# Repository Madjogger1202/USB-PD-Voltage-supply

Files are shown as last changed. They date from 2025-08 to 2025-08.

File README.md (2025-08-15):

# USB-PD Voltage supply

<table align="center">
  <tr>
    <td>
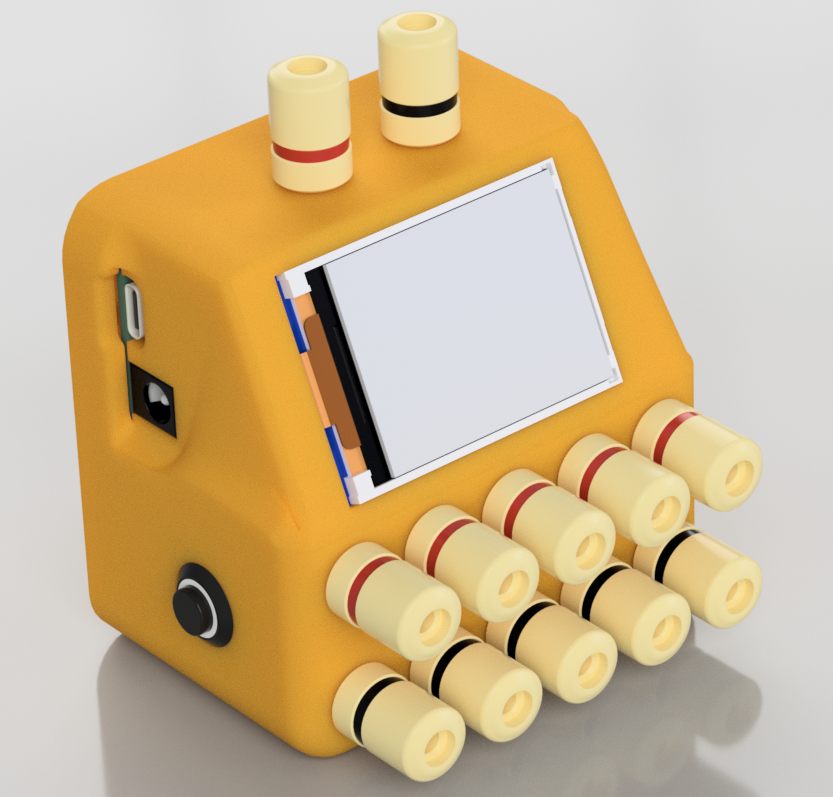
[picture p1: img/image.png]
      
    </td> 
    <td>
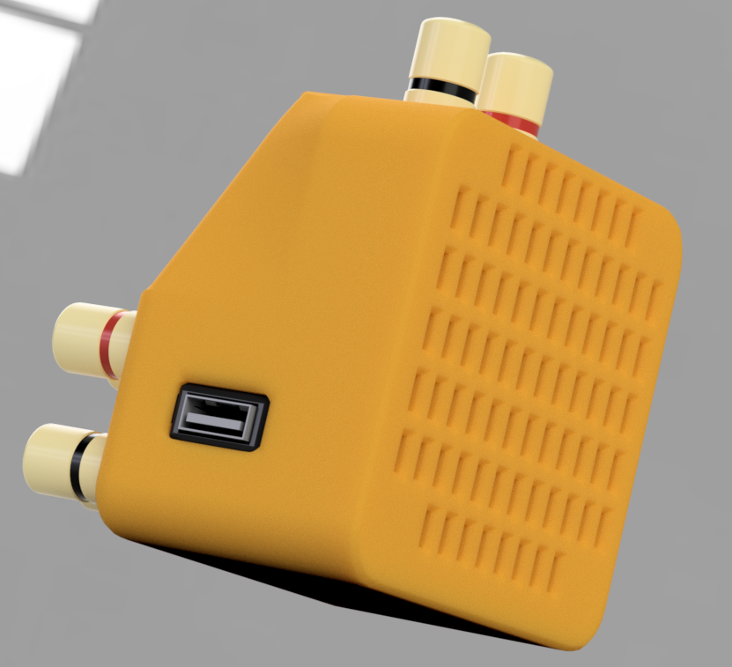
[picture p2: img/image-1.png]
      
    </td>
  </tr>
</table>

# Universal Programmable Power Supply Module

A compact, network-enabled power solution designed for debugging modern semiconductor components (e.g., PCIe switches, ASICs, and multi-voltage SoCs). Replaces traditional bench power supplies with a single integrated unit featuring precise voltage control, remote accessibility, and modular expandability.

---

> [!IMPORTANT]
> Project wasn't produced and tested yet.

## Key Features

- **Dual Adjustable DC-DC Outputs**  
  0.8–22 V, 6 A per channel (TPS55289RYQR controllers)  
- **Dual Fixed 5 V Outputs**  
  3 A each (LMR16030PDDAR), one for system logic, one for LDO input  
- **Low-Noise LDO Output**  
  0.5–5 V, 3 A (TPS7A5701RTER with TPL0501-100DCNR digital potentiometer)  
- **Universal Input**  
  Accepts 5–20 V via USB-C Power Delivery (STUSB4500QTR) or barrel jack (max 21 V input)  
- **Network Control**  
  ESP32-C3-based management with secure Wi-Fi/BLE, web interface, and Telegram bot  
- **Precision Monitoring**  
  ±1% current sensing via INA180A2 and ESP32-C3 ADC  
- **Expandable I/O**  
  Integrated GPIO expander for external modules or physical control buttons  
- **PCB Stackup**  
  4-layer board designed for stable power distribution, reduced noise, and improved thermal performance. Layers include dedicated power and ground planes for enhanced signal integrity. 
---

## Technical Specifications

| **Parameter** | **Details** |
|---|---|
| **Input** | USB-C PD (20 V/5 A) or 5.5×2.5 mm barrel jack (5–20 V) |
| **Adjustable Rails** | 2× 0.8–22 V / 6 A (DC-DC), 1× 0.5–5 V / 3 A (LDO) |
| **Fixed Rails** | 2× 5 V / 3 A (DC-DC) |
| **Control Interface**  | ESP32-C3 (Wi-Fi 4, BLE 5), REST API, web UI, Telegram bot |
| **Display** | 2.0" ST7789 (320×240) TFT with real-time voltage/current monitoring |
| **Current Sensing** | INA180A2 amplifier with 12-bit ADC resolution |
| **Safety Limits** | Input voltage ≤ 21 V; overcurrent/overvoltage protection per channel |

---

## PCB
<div align="center">
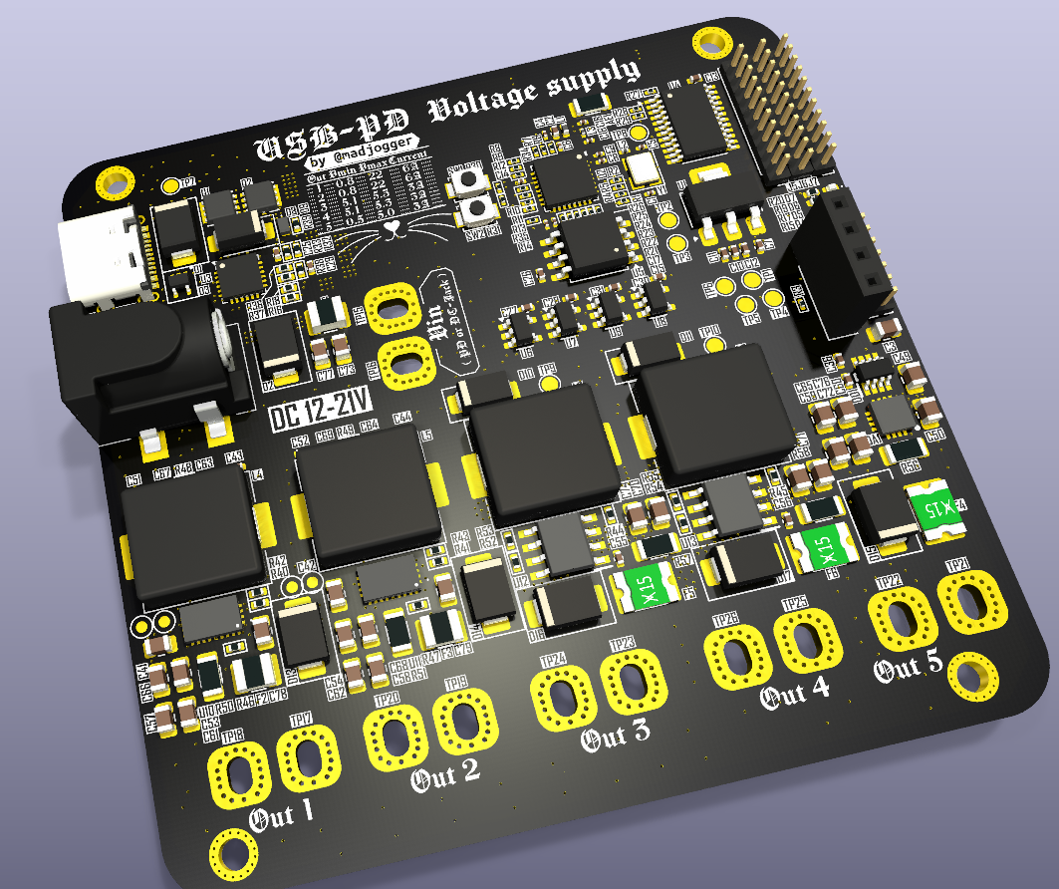
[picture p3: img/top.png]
Top view
  
  &nbsp;&nbsp;&nbsp;&nbsp;
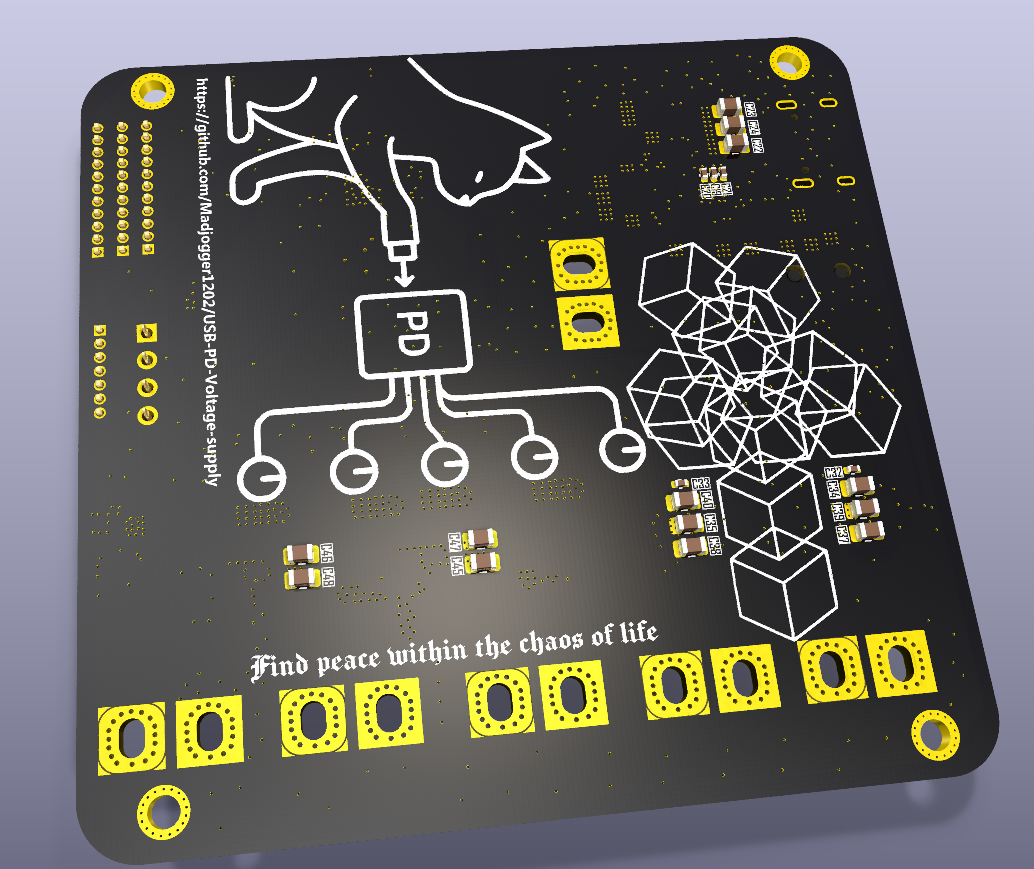
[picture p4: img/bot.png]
Bottom view
  
  &nbsp;&nbsp;&nbsp;&nbsp;
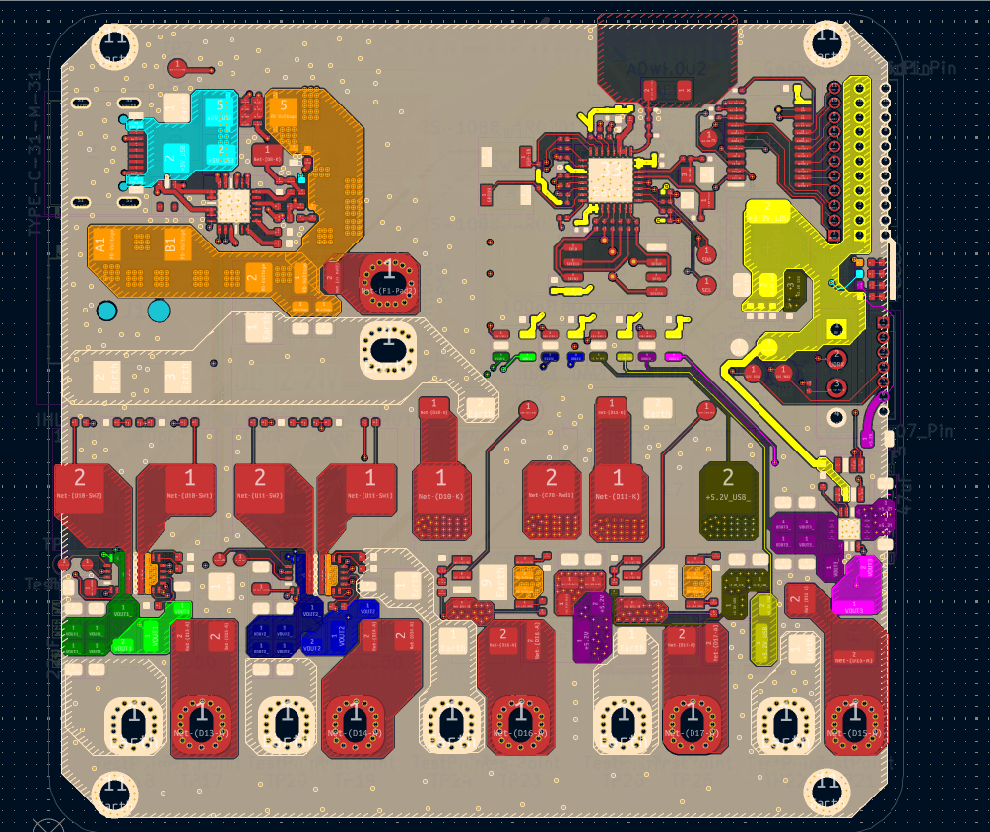
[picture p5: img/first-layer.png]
First layer
  
</div>

## Functional diagram
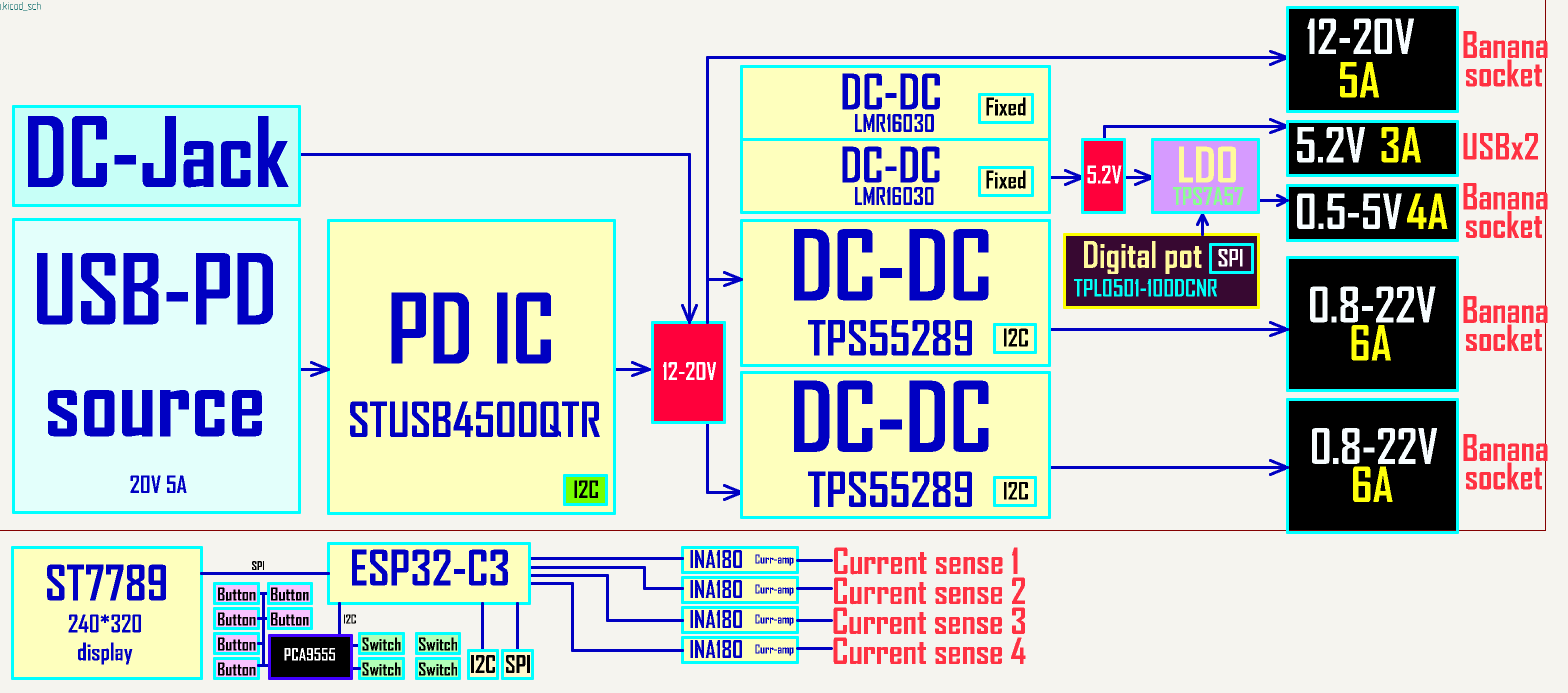
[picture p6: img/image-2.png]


## Standard Configuration

- 6× banana jack terminal pairs 
- 2.0" ST7789 color display (320×240 resolution)  
- USB-A port for peripheral connectivity  
- 12 mm illuminated push-button (power control)    

---

## Development Ecosystem

- **Schematic & PCB Design**: KiCad 9.0 (4-layer stackup)  
- **3D Modeling**: Fusion 360 
- **Firmware**: PlatformIO (Arduino)  

---

## Use Cases

- General-purpose bench power supply
- PCIe switch and high-speed interface debugging  
- Multi-rail ASIC/FPGA prototyping  
- Low-noise analog/digital mixed-signal validation  
- Automated test environments requiring remote power cycling  

---

## Documentation

  - [Schematics](USB-PD-Voltage-supply.pdf)  
  - [Interactive HTML BOM](BOM/USB-PD-Voltage-supply-Interactive-BOM.html)  
  - [3D model with case](3D/USB-PD-Voltage-supply-with-case.step)  
  - Code for PlatformIO coming soon

> **Note**: Input voltage must not exceed 21 V. Always verify load requirements before operation.

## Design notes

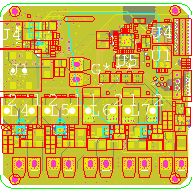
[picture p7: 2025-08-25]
USB-PD-Voltage-supply simulation/USB-PD-Voltage-supply simulation/Model/DS/Image/Model.bmp

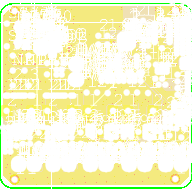
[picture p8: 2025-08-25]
USB-PD-Voltage-supply simulation/USB-PD-Voltage-supply simulation/Model/PCBS/Model.bmp

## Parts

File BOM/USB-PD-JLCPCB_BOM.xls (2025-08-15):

Comment | Designator | Footprint | JLCPCB Part#(optional)
ADWH002 | AE1 | 1206_3216Metric | C22467691
24pF | C1,C5 | 0201_0603Metric | C285108
10uF | C2,C11 | 0402_1005Metric | C76991
22uF 25V | C3,C22,C23,C24,C34,C35,C37,C38,C39,C40,C41,C42,C45,C46,C47,C48,C53,C54,C57,C58,C61,C62,C66,C68,C73,C77,C78,C79 | 0805_2012Metric | C45783
100nF | C4,C8,C14,C15 | 0201_0603Metric | C49062
1uF | C6,C9,C17 | 0201_0603Metric | C53067
22uF | C7,C10 | 0402_1005Metric | C105226
100nF | C12,C13,C26,C27,C28,C29,C30,C31,C32,C33,C36,C43,C44,C51,C52,C55,C56 | 0402_1005Metric | C1581
1.2pF | C16 | 0201_0603Metric | C85895
1.8pF | C18 | 0201_0603Metric | C285155
1uF | C19,C20,C21,C25 | 0402_1005Metric | C77009
47uF | C49,C50,C59,C65,C70,C71,C72,C74,C75,C76 | 0805_2012Metric | C16780
4.7uF | C60 | 0402_1005Metric | C5718966
10pF | C63,C64 | 0402_1005Metric | C1545
2.2nF | C67,C69 | 0402_1005Metric | C1531
SMBJ40CA | D1,D2,D13,D14,D15,D16,D17 | SMB | C726876
ESDA25W5 | D3 | SOT-353 | C2931117
LED | D4,D5,D6,D7 | 402 | C71911
SS34 | D8,D10,D11 | SMA | C8678
ESDA25P35-1U1M | D9 | ESDA25P35-1U1M:ESDA25P351U1M | C1974707
TPS7A5701RTER | DA1 | TPS7A57:TPS7A57 | C5220126
TPL0501-100DCNR | DD1 | TPL0501-100DCNR:SOT65P280X145-8N | C131323
SL1210650 | F1,F2,F3 | Fuse:Fuse_1210_3225Metric | C70191
SMD1812P350TF | F4,F5,F6 | Fuse:Fuse_1812_4532Metric | C20815
DC-005-5A-2.5-SMT | J1 | DC-005-5A:DC-005-5A | C319133
Conn_01x07_Pin | J2 | Connector_PinHeader_1.27mm:PinHeader_1x07_P1.27mm_Vertical | C22438104
Conn_01x04_Pin | J3 | Connector_PinSocket_2.54mm:PinSocket_1x04_P2.54mm_Vertical | C5116483
TYPE-C-31-M-31 | J4 | Connector_USB:USB_C_Receptacle_G-Switch_GT-USB-7010ASV | C2760486
2nH | L1 | Inductor_SMD:L_0402_1005Metric | C76769
24nH | L2 | Inductor_SMD:L_0201_0603Metric | C206441
3nH | L3 | Inductor_SMD:L_0201_0603Metric | C87524
IHLP4040DZER4R7M01 | L4,L5 | Inductor_SMD:L_APV_APH1040 | C845077
IHLP4040DZER100M01 | L6,L7 | Inductor_SMD:L_APV_APH1040 | C845065
STL6P3LLH6 | Q1,Q2 | STL6P3LLH6:STL8N10F7 | C22366875
4.7K | R1,R2 | PCM_Resistor_SMD_AKL:R_0402_1005Metric | C25900
499 | R3 | PCM_Resistor_SMD_AKL:R_0201_0603Metric | C4125
0 | R4,R5,R6,R7,R8,R9,R10,R11,R12,R13,R14,R21,R22,R23,R24,R25,R26,R27,R28,R29 | PCM_Resistor_SMD_AKL:R_0201_0603Metric | C17168
620 | R15 | 0402_1005Metric | C4961
100K | R16,R18,R37,R52,R54 | PCM_Resistor_SMD_AKL:R_0402_1005Metric | C25741
1.5K | R17 | 0402_1005Metric | C25867
10K | R19,R20 | 0402_1005Metric | C25744
10K | R30,R31 | PCM_Resistor_SMD_AKL:R_0201_0603Metric | C100126
470 | R32 | PCM_Resistor_SMD_AKL:R_0402_1005Metric | C25117
1K | R33,R39 | PCM_Resistor_SMD_AKL:R_0402_1005Metric | C11702
100K | R34,R35 | PCM_Resistor_SMD_AKL:R_0201_0603Metric | C100127
22K | R36 | PCM_Resistor_SMD_AKL:R_0402_1005Metric | C25768
100 | R38 | PCM_Resistor_SMD_AKL:R_0402_1005Metric | C25076
0 | R40,R41 | PCM_Resistor_SMD_AKL:R_0402_1005Metric | C17168
82K | R42,R43 | PCM_Resistor_SMD_AKL:R_0402_1005Metric | C4142
49.9K | R44,R45 | PCM_Resistor_SMD_AKL:R_0402_1005Metric | C25897
10K | R46,R47 | PCM_Resistor_SMD_AKL:R_0402_1005Metric | C25531
71.5K | R48,R49 | PCM_Resistor_SMD_AKL:R_0402_1005Metric | C273328
0.01 | R50,R51,R56,R57,R58 | 1206_3216Metric | C364375
16.9K | R53,R55 | PCM_Resistor_SMD_AKL:R_0402_1005Metric | C25858
TS-1088-AR02016 | SW1,SW2 | Button_Switch_SMD:SW_SPST_B3U-1000P | C720477
AP1117-33 | U1 | Package_TO_SOT_SMD:SOT-223-3_TabPin2 | C5400
ESP32-C3 | U2 | Package_DFN_QFN:QFN-32-1EP_5x5mm_P0.5mm_EP3.7x3.7mm | C2838500
STUSB4500QTR | U3 | Package_DFN_QFN:QFN-24-1EP_4x4mm_P0.5mm_EP2.7x2.7mm | STUSB4500QTR
PCA9555PW | U4 | Package_SO:TSSOP-24_4.4x7.8mm_P0.65mm | C128392
W25Q128JVS | U5 | Package_SO:SOIC-8_5.3x5.3mm_P1.27mm | C97521
INA180A2 | U6,U7,U8,U9 | Package_TO_SOT_SMD:SOT-23-5 | SOT-23-5
TPS55289RYQR | U10,U11 | TPS55289RYQR:TPS55289RYQR | C5942077
LMR16030PDDAR | U12,U13 | LMR16030:LMR16030 | C90665
X322540MPB4SI | Y1 | Crystal:Crystal_SMD_3225-4Pin_3.2x2.5mm | C9010

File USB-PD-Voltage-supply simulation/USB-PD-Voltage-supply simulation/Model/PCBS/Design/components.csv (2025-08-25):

refdes | partname | type | Arrow_Part_Number | Arrow_Price/Stock | Datasheet | Description | Height | Manufacturer_Name | Manufacturer_Part_Number | Mouser_Part_Number | Mouser_Price/Stock | Value | Voltage
AE1 | Resistor_SMD_R_1206_3216Metric |  |  |  |  | Ceramic chip antenna with pin for PCB trace |  |  |  |  |  | ADWH002
C1 | Capacitor_SMD_C_0201_0603Metric | C |  |  |  | Unpolarized capacitor |  |  |  |  |  | 24pF
C10 | Capacitor_SMD_C_0402_1005Metric | C |  |  |  | Unpolarized capacitor |  |  |  |  |  | 22uF
C11 | Capacitor_SMD_C_0402_1005Metric | C |  |  |  | Unpolarized capacitor |  |  |  |  |  | 10uF
C12 | Capacitor_SMD_C_0402_1005Metric | C |  |  |  | Unpolarized capacitor |  |  |  |  |  | 100nF
C13 | Capacitor_SMD_C_0402_1005Metric | C |  |  |  | Unpolarized capacitor |  |  |  |  |  | 100nF
C14 | Capacitor_SMD_C_0201_0603Metric | C |  |  |  | Unpolarized capacitor |  |  |  |  |  | 100nF
C15 | Capacitor_SMD_C_0201_0603Metric | C |  |  |  | Unpolarized capacitor |  |  |  |  |  | 100nF
C16 | Capacitor_SMD_C_0201_0603Metric | C |  |  |  | Unpolarized capacitor |  |  |  |  |  | 1.2pF
C17 | Capacitor_SMD_C_0201_0603Metric | C |  |  |  | Unpolarized capacitor |  |  |  |  |  | 1uF
C18 | Capacitor_SMD_C_0201_0603Metric | C |  |  |  | Unpolarized capacitor |  |  |  |  |  | 1.8pF
C2 | Capacitor_SMD_C_0402_1005Metric | C |  |  |  | Unpolarized capacitor |  |  |  |  |  | 10uF
C25 | Capacitor_SMD_C_0402_1005Metric | C |  |  |  | Unpolarized capacitor |  |  |  |  |  | 1uF
C26 | Capacitor_SMD_C_0402_1005Metric | C |  |  |  | Unpolarized capacitor |  |  |  |  |  | 100nF
C27 | Capacitor_SMD_C_0402_1005Metric | C |  |  |  | Unpolarized capacitor |  |  |  |  |  | 100nF
C28 | Capacitor_SMD_C_0402_1005Metric | C |  |  |  | Unpolarized capacitor |  |  |  |  |  | 100nF
C29 | Capacitor_SMD_C_0402_1005Metric | C |  |  |  | Unpolarized capacitor |  |  |  |  |  | 100nF
C3 | Capacitor_SMD_C_0805_2012Metric | C |  |  |  | Unpolarized capacitor |  |  |  |  |  | 22uF | 25V
C30 | Capacitor_SMD_C_0402_1005Metric | C |  |  |  | Unpolarized capacitor |  |  |  |  |  | 100nF
C31 | Capacitor_SMD_C_0402_1005Metric | C |  |  |  | Unpolarized capacitor |  |  |  |  |  | 100nF
C36 | Capacitor_SMD_C_0402_1005Metric | C |  |  |  | Unpolarized capacitor |  |  |  |  |  | 100nF
C4 | Capacitor_SMD_C_0201_0603Metric | C |  |  |  | Unpolarized capacitor |  |  |  |  |  | 100nF
C41 | Capacitor_SMD_C_0805_2012Metric | C |  |  |  | Unpolarized capacitor |  |  |  |  |  | 22uF | 25V
C42 | Capacitor_SMD_C_0805_2012Metric | C |  |  |  | Unpolarized capacitor |  |  |  |  |  | 22uF | 25V
C43 | Capacitor_SMD_C_0402_1005Metric | C |  |  |  | Unpolarized capacitor |  |  |  |  |  | 100nF
C44 | Capacitor_SMD_C_0402_1005Metric | C |  |  |  | Unpolarized capacitor |  |  |  |  |  | 100nF
C49 | Capacitor_SMD_C_0805_2012Metric | C |  |  |  | Unpolarized capacitor |  |  |  |  |  | 47uF | 6.3V
C5 | Capacitor_SMD_C_0201_0603Metric | C |  |  |  | Unpolarized capacitor |  |  |  |  |  | 24pF
C50 | Capacitor_SMD_C_0805_2012Metric | C |  |  |  | Unpolarized capacitor |  |  |  |  |  | 47uF | 6.3V
C51 | Capacitor_SMD_C_0402_1005Metric | C |  |  |  | Unpolarized capacitor |  |  |  |  |  | 100nF
C52 | Capacitor_SMD_C_0402_1005Metric | C |  |  |  | Unpolarized capacitor |  |  |  |  |  | 100nF
C53 | Capacitor_SMD_C_0805_2012Metric | C |  |  |  | Unpolarized capacitor |  |  |  |  |  | 22uF | 25V
C54 | Capacitor_SMD_C_0805_2012Metric | C |  |  |  | Unpolarized capacitor |  |  |  |  |  | 22uF | 25V
C55 | Capacitor_SMD_C_0402_1005Metric | C |  |  |  | Unpolarized capacitor |  |  |  |  |  | 100nF
C56 | Capacitor_SMD_C_0402_1005Metric | C |  |  |  | Unpolarized capacitor |  |  |  |  |  | 100nF
C57 | Capacitor_SMD_C_0805_2012Metric | C |  |  |  | Unpolarized capacitor |  |  |  |  |  | 22uF | 25V
C58 | Capacitor_SMD_C_0805_2012Metric | C |  |  |  | Unpolarized capacitor |  |  |  |  |  | 22uF | 25V
C59 | Capacitor_SMD_C_0805_2012Metric | C |  |  |  | Unpolarized capacitor |  |  |  |  |  | 47uF | 6.3V
C6 | Capacitor_SMD_C_0201_0603Metric | C |  |  |  | Unpolarized capacitor |  |  |  |  |  | 1uF
C60 | Capacitor_SMD_C_0402_1005Metric | C |  |  |  | Unpolarized capacitor |  |  |  |  |  | 4.7uF | 6.3V
C61 | Capacitor_SMD_C_0805_2012Metric | C |  |  |  | Unpolarized capacitor |  |  |  |  |  | 22uF | 25V
C62 | Capacitor_SMD_C_0805_2012Metric | C |  |  |  | Unpolarized capacitor |  |  |  |  |  | 22uF | 25V
C63 | Capacitor_SMD_C_0402_1005Metric | C |  |  |  | Unpolarized capacitor |  |  |  |  |  | 10pF
C64 | Capacitor_SMD_C_0402_1005Metric | C |  |  |  | Unpolarized capacitor |  |  |  |  |  | 10pF
C65 | Capacitor_SMD_C_0805_2012Metric | C |  |  |  | Unpolarized capacitor |  |  |  |  |  | 47uF | 6.3V
C66 | Capacitor_SMD_C_0805_2012Metric | C |  |  |  | Unpolarized capacitor |  |  |  |  |  | 22uF | 25V
C67 | Capacitor_SMD_C_0402_1005Metric | C |  |  |  | Unpolarized capacitor |  |  |  |  |  | 2.2nF
C68 | Capacitor_SMD_C_0805_2012Metric | C |  |  |  | Unpolarized capacitor |  |  |  |  |  | 22uF | 25V
C69 | Capacitor_SMD_C_0402_1005Metric | C |  |  |  | Unpolarized capacitor |  |  |  |  |  | 2.2nF
C7 | Capacitor_SMD_C_0402_1005Metric | C |  |  |  | Unpolarized capacitor |  |  |  |  |  | 22uF
C70 | Capacitor_SMD_C_0805_2012Metric | C |  |  |  | Unpolarized capacitor |  |  |  |  |  | 47uF | 6.3V
C71 | Capacitor_SMD_C_0805_2012Metric | C |  |  |  | Unpolarized capacitor |  |  |  |  |  | 47uF | 6.3V
C72 | Capacitor_SMD_C_0805_2012Metric | C |  |  |  | Unpolarized capacitor |  |  |  |  |  | 47uF | 6.3V
C73 | Capacitor_SMD_C_0805_2012Metric | C |  |  |  | Unpolarized capacitor |  |  |  |  |  | 22uF | 25V
C74 | Capacitor_SMD_C_0805_2012Metric | C |  |  |  | Unpolarized capacitor |  |  |  |  |  | 47uF | 6.3V
C75 | Capacitor_SMD_C_0805_2012Metric | C |  |  |  | Unpolarized capacitor |  |  |  |  |  | 47uF | 6.3V
C76 | Capacitor_SMD_C_0805_2012Metric | C |  |  |  | Unpolarized capacitor |  |  |  |  |  | 47uF | 6.3V
C77 | Capacitor_SMD_C_0805_2012Metric | C |  |  |  | Unpolarized capacitor |  |  |  |  |  | 22uF | 25V
C78 | Capacitor_SMD_C_0805_2012Metric | C |  |  |  | Unpolarized capacitor |  |  |  |  |  | 22uF | 25V
C79 | Capacitor_SMD_C_0805_2012Metric | C |  |  |  | Unpolarized capacitor |  |  |  |  |  | 22uF | 25V
C8 | Capacitor_SMD_C_0201_0603Metric | C |  |  |  | Unpolarized capacitor |  |  |  |  |  | 100nF
C9 | Capacitor_SMD_C_0201_0603Metric | C |  |  |  | Unpolarized capacitor |  |  |  |  |  | 1uF
D1 | PCM_Diode_SMD_AKL_D_SMB_TVS |  |  |  | https://www.tme.eu/Document/0b6222bec7e12d83185b51d73cb6a54d/SMBJ_ser.pdf | SMB Bidirectional TVS Diode, 40V, 600W, Alternate KiCAD Library |  |  |  |  |  | SMBJ40CA
D10 | Diode_SMD_D_SMA |  |  |  | https://www.tme.eu/Document/4534c3d1273464918563ce78bdeb2ece/SS34-E3-57T.pdf | SMC Schottky diode, 40V, 3A, Alternate KiCAD Library |  |  |  |  |  | SS34
D11 | Diode_SMD_D_SMA |  |  |  | https://www.tme.eu/Document/4534c3d1273464918563ce78bdeb2ece/SS34-E3-57T.pdf | SMC Schottky diode, 40V, 3A, Alternate KiCAD Library |  |  |  |  |  | SS34
D13 | PCM_Diode_SMD_AKL_D_SMB_TVS |  |  |  | https://www.tme.eu/Document/0b6222bec7e12d83185b51d73cb6a54d/SMBJ_ser.pdf | SMB Bidirectional TVS Diode, 40V, 600W, Alternate KiCAD Library |  |  |  |  |  | SMBJ40CA
D14 | PCM_Diode_SMD_AKL_D_SMB_TVS |  |  |  | https://www.tme.eu/Document/0b6222bec7e12d83185b51d73cb6a54d/SMBJ_ser.pdf | SMB Bidirectional TVS Diode, 40V, 600W, Alternate KiCAD Library |  |  |  |  |  | SMBJ40CA
D15 | PCM_Diode_SMD_AKL_D_SMB_TVS |  |  |  | https://www.tme.eu/Document/0b6222bec7e12d83185b51d73cb6a54d/SMBJ_ser.pdf | SMB Bidirectional TVS Diode, 40V, 600W, Alternate KiCAD Library |  |  |  |  |  | SMBJ40CA
D16 | PCM_Diode_SMD_AKL_D_SMB_TVS |  |  |  | https://www.tme.eu/Document/0b6222bec7e12d83185b51d73cb6a54d/SMBJ_ser.pdf | SMB Bidirectional TVS Diode, 40V, 600W, Alternate KiCAD Library |  |  |  |  |  | SMBJ40CA
D17 | PCM_Diode_SMD_AKL_D_SMB_TVS |  |  |  | https://www.tme.eu/Document/0b6222bec7e12d83185b51d73cb6a54d/SMBJ_ser.pdf | SMB Bidirectional TVS Diode, 40V, 600W, Alternate KiCAD Library |  |  |  |  |  | SMBJ40CA
D2 | PCM_Diode_SMD_AKL_D_SMB_TVS |  |  |  | https://www.tme.eu/Document/0b6222bec7e12d83185b51d73cb6a54d/SMBJ_ser.pdf | SMB Bidirectional TVS Diode, 40V, 600W, Alternate KiCAD Library |  |  |  |  |  | SMBJ40CA
D3 | PCM_Package_TO_SOT_SMD_AKL_SOT-353_SC-70-5 |  |  |  | https://www.tme.eu/Document/d23152a24a9b38ad8c9675e4388f9442/ESDAxxxWx.pdf | SOT-353 TVS Diode array, 4xUnidirectional, 25V, 150W, Alternate KiCAD Library |  |  |  |  |  | ESDA25W5
D4 | LED_SMD_LED_0402_1005Metric |  |  |  |  | Light emitting diode |  |  |  |  |  | LED
D5 | LED_SMD_LED_0402_1005Metric |  |  |  |  | Light emitting diode |  |  |  |  |  | LED
D6 | LED_SMD_LED_0402_1005Metric |  |  |  |  | Light emitting diode |  |  |  |  |  | LED
D7 | LED_SMD_LED_0402_1005Metric |  |  |  |  | Light emitting diode |  |  |  |  |  | LED
D8 | Diode_SMD_D_SMA |  |  |  | https://www.tme.eu/Document/4534c3d1273464918563ce78bdeb2ece/SS34-E3-57T.pdf | SMC Schottky diode, 40V, 3A, Alternate KiCAD Library |  |  |  |  |  | SS34
D9 | ESDA25P35-1U1M_ESDA25P351U1M |  | ESDA25P35-1U1M | https://www.arrow.com/en/products/esda25p35-1u1m/stmicroelectronics?utm_currency=USD&region=europe | https://www.st.com/resource/en/datasheet/esda25p35-1u1m.pdf | STMicroelectronics ESDA25P35-1U1M, Uni-Directional TVS Diode, 1400W, 2-Pin QFN | 0.6 | STMicroelectronics | ESDA25P35-1U1M | 511-ESDA25P35-1U1M | https://www.mouser.co.uk/ProductDetail/STMicroelectronics/ESDA25P35-1U1M?qs=aVyJF2WnouQUWqgNP85ZrA%3D%3D | ESDA25P35-1U1M
DA1 | TPS7A57_TPS7A57 |  |  |  | https://www.mouser.in/ProductDetail/Texas-Instruments/TPS7A5701RTER?qs=vvQtp7zwQdOmK5SKE0o8WA%3D%3D | LDO Voltage Regulators 5-A, low-VIN, low-noise, high-accuracy low-dropout (LDO) voltage regulator | 0.8 | Texas Instruments | TPS7A5701RTER | 595-TPS7A5701RTER | https://www.mouser.co.uk/ProductDetail/Texas-Instruments/TPS7A5701RTER?qs=vvQtp7zwQdOmK5SKE0o8WA%3D%3D | TPS7A5701RTER
DD1 | TPL0501-100DCNR_SOT65P280X145-8N |  | TPL0501-100DCNR | https://www.arrow.com/en/products/tpl0501-100dcnr/texas-instruments?region=nac | http://www.ti.com/lit/gpn/tpl0501-100 | TPL0501-100DCNR, Digital Potentiometer 120k 256-Position Linear Serial-3 Wire, Serial-SPI 8-Pin SOT-23 | 1.45 | Texas Instruments | TPL0501-100DCNR | 595-TPL0501-100DCNR | https://www.mouser.co.uk/ProductDetail/Texas-Instruments/TPL0501-100DCNR?qs=QtI0yD1FyONqFe2CXN2fCQ%3D%3D | TPL0501-100DCNR
F1 | Fuse_Fuse_1210_3225Metric |  |  |  |  | Resettable fuse, polymeric positive temperature coefficient |  |  |  |  |  | SL1210650
F2 | Fuse_Fuse_1210_3225Metric |  |  |  |  | Resettable fuse, polymeric positive temperature coefficient |  |  |  |  |  | SL1210650
F3 | Fuse_Fuse_1210_3225Metric |  |  |  |  | Resettable fuse, polymeric positive temperature coefficient |  |  |  |  |  | SL1210650
F4 | Fuse_Fuse_1812_4532Metric |  |  |  |  | Resettable fuse, polymeric positive temperature coefficient |  |  |  |  |  | SMD1812P350TF
F5 | Fuse_Fuse_1812_4532Metric |  |  |  |  | Resettable fuse, polymeric positive temperature coefficient |  |  |  |  |  | SMD1812P350TF
F6 | Fuse_Fuse_1812_4532Metric |  |  |  |  | Resettable fuse, polymeric positive temperature coefficient |  |  |  |  |  | SMD1812P350TF
G*** | _LOGO |  |  |  |  |  |  |  |  |  |  | LOGO
J1 | DC-005-5A_DC-005-5A |  |  |  | https://datasheet.lcsc.com/szlcsc/XKB-DC-005-5A-2-5-SMT_C319133.pdf | DC Power Jack | 11 | XKB Connectivity | DC-005-5A-2.5-SMT |  |  | DC-005-5A-2.5-SMT
J2 | Connector_PinHeader_1.27mm_PinHeader_1x07_P1.27mm_Vertical |  |  |  |  | Generic connector, single row, 01x07, script generated |  |  |  |  |  | Conn_01x07_Pin
J3 | Connector_PinSocket_2.54mm_PinSocket_1x04_P2.54mm_Vertical |  |  |  |  | Generic connector, single row, 01x04, script generated |  |  |  |  |  | Conn_01x04_Pin
J4 | Connector_USB_USB_C_Receptacle_G-Switch_GT-USB-7010ASV |  |  |  | https://www.usb.org/sites/default/files/documents/usb_type-c.zip | USB 2.0-only 16P Type-C Receptacle connector |  |  |  |  |  | TYPE-C-31-M-31
J5 | Connector_PinHeader_1.27mm_PinHeader_1x11_P1.27mm_Vertical |  |  |  |  | Generic connector, single row, 01x11, script generated |  |  |  |  |  | Conn_01x11_Pin
J6 | Connector_PinHeader_1.27mm_PinHeader_1x11_P1.27mm_Vertical |  |  |  |  | Generic connector, single row, 01x11, script generated |  |  |  |  |  | Conn_01x11_Pin
J7 | Connector_PinHeader_1.27mm_PinHeader_1x11_P1.27mm_Vertical |  |  |  |  | Generic connector, single row, 01x11, script generated |  |  |  |  |  | Conn_01x11_Pin
L1 | Inductor_SMD_L_0402_1005Metric | L |  |  |  | Inductor |  |  |  |  |  | 2nH
L2 | Inductor_SMD_L_0201_0603Metric | L |  |  |  | Inductor |  |  |  |  |  | 24nH
L3 | Inductor_SMD_L_0201_0603Metric | L |  |  |  | Inductor |  |  |  |  |  | 3nH
L4 | Inductor_SMD_L_APV_APH1040 | L |  |  |  | Inductor |  |  |  |  |  | IHLP4040DZER4R7M01
L5 | Inductor_SMD_L_APV_APH1040 | L |  |  |  | Inductor |  |  |  |  |  | IHLP4040DZER4R7M01
L6 | Inductor_SMD_L_APV_APH1040 | L |  |  |  | Inductor |  |  |  |  |  | IHLP4040DZER100M01
L7 | Inductor_SMD_L_APV_APH1040 | L |  |  |  | Inductor |  |  |  |  |  | IHLP4040DZER100M01
Q1 | STL6P3LLH6_STL8N10F7 |  | STL6P3LLH6 | https://www.arrow.com/en/products/stl6p3llh6/stmicroelectronics?utm_currency=USD&region=nac | https://www.mouser.com/datasheet/2/389/stl6p3llh6-1851075.pdf | MOSFET P-channel 30 V, 0.024 Ohm typ., 6 A STripFET H6 Power MOSFET in a PowerFLAT 3.3 x 3.3 package | 0.9 | STMicroelectronics | STL6P3LLH6 | 511-STL6P3LLH6 | https://www.mouser.co.uk/ProductDetail/STMicroelectronics/STL6P3LLH6?qs=DqCdCwOw4%2F6Sn4l3cEaG7Q%3D%3D | STL6P3LLH6
Q2 | STL6P3LLH6_STL8N10F7 |  | STL6P3LLH6 | https://www.arrow.com/en/products/stl6p3llh6/stmicroelectronics?utm_currency=USD&region=nac | https://www.mouser.com/datasheet/2/389/stl6p3llh6-1851075.pdf | MOSFET P-channel 30 V, 0.024 Ohm typ., 6 A STripFET H6 Power MOSFET in a PowerFLAT 3.3 x 3.3 package | 0.9 | STMicroelectronics | STL6P3LLH6 | 511-STL6P3LLH6 | https://www.mouser.co.uk/ProductDetail/STMicroelectronics/STL6P3LLH6?qs=DqCdCwOw4%2F6Sn4l3cEaG7Q%3D%3D | STL6P3LLH6
R1 | PCM_Resistor_SMD_AKL_R_0201_0603Metric | R |  |  |  | Resistor |  |  |  |  |  | 4.7K
R10 | PCM_Resistor_SMD_AKL_R_0201_0603Metric | R |  |  |  | Resistor |  |  |  |  |  | 0
R11 | PCM_Resistor_SMD_AKL_R_0201_0603Metric | R |  |  |  | Resistor |  |  |  |  |  | 0
R12 | PCM_Resistor_SMD_AKL_R_0201_0603Metric | R |  |  |  | Resistor |  |  |  |  |  | 0
R13 | PCM_Resistor_SMD_AKL_R_0201_0603Metric | R |  |  |  | Resistor |  |  |  |  |  | 0
R14 | PCM_Resistor_SMD_AKL_R_0201_0603Metric | R |  |  |  | Resistor |  |  |  |  |  | 0
R15 | Resistor_SMD_R_0402_1005Metric | R |  |  |  | Resistor |  |  |  |  |  | 620
R16 | PCM_Resistor_SMD_AKL_R_0402_1005Metric | R |  |  |  | Resistor |  |  |  |  |  | 100K
R17 | Resistor_SMD_R_0402_1005Metric | R |  |  |  | Resistor |  |  |  |  |  | 1.5K
R18 | PCM_Resistor_SMD_AKL_R_0402_1005Metric | R |  |  |  | Resistor |  |  |  |  |  | 100K
R19 | Resistor_SMD_R_0402_1005Metric | R |  |  |  | Resistor |  |  |  |  |  | 10K
R2 | PCM_Resistor_SMD_AKL_R_0201_0603Metric | R |  |  |  | Resistor |  |  |  |  |  | 4.7K
R20 | Resistor_SMD_R_0402_1005Metric | R |  |  |  | Resistor |  |  |  |  |  | 10K
R21 | PCM_Resistor_SMD_AKL_R_0201_0603Metric | R |  |  |  | Resistor |  |  |  |  |  | 0
R22 | PCM_Resistor_SMD_AKL_R_0201_0603Metric | R |  |  |  | Resistor |  |  |  |  |  | 0
R23 | PCM_Resistor_SMD_AKL_R_0201_0603Metric | R |  |  |  | Resistor |  |  |  |  |  | 0
R24 | PCM_Resistor_SMD_AKL_R_0201_0603Metric | R |  |  |  | Resistor |  |  |  |  |  | 0
R25 | PCM_Resistor_SMD_AKL_R_0201_0603Metric | R |  |  |  | Resistor |  |  |  |  |  | 0
R26 | PCM_Resistor_SMD_AKL_R_0201_0603Metric | R |  |  |  | Resistor |  |  |  |  |  | 0
R27 | PCM_Resistor_SMD_AKL_R_0201_0603Metric | R |  |  |  | Resistor |  |  |  |  |  | 0
R28 | PCM_Resistor_SMD_AKL_R_0201_0603Metric | R |  |  |  | Resistor |  |  |  |  |  | 0
R29 | PCM_Resistor_SMD_AKL_R_0201_0603Metric | R |  |  |  | Resistor |  |  |  |  |  | 0
R3 | PCM_Resistor_SMD_AKL_R_0201_0603Metric | R |  |  |  | Resistor |  |  |  |  |  | 499
R30 | PCM_Resistor_SMD_AKL_R_0201_0603Metric | R |  |  |  | Resistor |  |  |  |  |  | 10K
R31 | PCM_Resistor_SMD_AKL_R_0201_0603Metric | R |  |  |  | Resistor |  |  |  |  |  | 10K
R32 | PCM_Resistor_SMD_AKL_R_0402_1005Metric | R |  |  |  | Resistor |  |  |  |  |  | 470
R33 | PCM_Resistor_SMD_AKL_R_0402_1005Metric | R |  |  |  | Resistor |  |  |  |  |  | 1K
R34 | PCM_Resistor_SMD_AKL_R_0201_0603Metric | R |  |  |  | Resistor |  |  |  |  |  | 100K
R35 | PCM_Resistor_SMD_AKL_R_0201_0603Metric | R |  |  |  | Resistor |  |  |  |  |  | 100K
R36 | PCM_Resistor_SMD_AKL_R_0402_1005Metric | R |  |  |  | Resistor |  |  |  |  |  | 22K
R37 | PCM_Resistor_SMD_AKL_R_0402_1005Metric | R |  |  |  | Resistor |  |  |  |  |  | 100K
R38 | PCM_Resistor_SMD_AKL_R_0402_1005Metric | R |  |  |  | Resistor |  |  |  |  |  | 100
R39 | PCM_Resistor_SMD_AKL_R_0402_1005Metric | R |  |  |  | Resistor |  |  |  |  |  | 1K
R4 | PCM_Resistor_SMD_AKL_R_0201_0603Metric | R |  |  |  | Resistor |  |  |  |  |  | 0
R40 | PCM_Resistor_SMD_AKL_R_0402_1005Metric | R |  |  |  | Resistor |  |  |  |  |  | 0
R41 | PCM_Resistor_SMD_AKL_R_0402_1005Metric | R |  |  |  | Resistor |  |  |  |  |  | 0
R42 | PCM_Resistor_SMD_AKL_R_0402_1005Metric | R |  |  |  | Resistor |  |  |  |  |  | 82K
R43 | PCM_Resistor_SMD_AKL_R_0402_1005Metric | R |  |  |  | Resistor |  |  |  |  |  | 82K
R44 | PCM_Resistor_SMD_AKL_R_0402_1005Metric | R |  |  |  | Resistor |  |  |  |  |  | 49.9K
R45 | PCM_Resistor_SMD_AKL_R_0402_1005Metric | R |  |  |  | Resistor |  |  |  |  |  | 49.9K
R46 | PCM_Resistor_SMD_AKL_R_0402_1005Metric | R |  |  |  | Resistor |  |  |  |  |  | 10K
R47 | PCM_Resistor_SMD_AKL_R_0402_1005Metric | R |  |  |  | Resistor |  |  |  |  |  | 10K
R48 | PCM_Resistor_SMD_AKL_R_0402_1005Metric | R |  |  |  | Resistor |  |  |  |  |  | 71.5K
R49 | PCM_Resistor_SMD_AKL_R_0402_1005Metric | R |  |  |  | Resistor |  |  |  |  |  | 71.5K
R5 | PCM_Resistor_SMD_AKL_R_0201_0603Metric | R |  |  |  | Resistor |  |  |  |  |  | 0
R50 | Resistor_SMD_R_1206_3216Metric | R |  |  |  | FRM121WFR010TM |  |  |  |  |  | 0.01
R51 | Resistor_SMD_R_1206_3216Metric | R |  |  |  | FRM121WFR010TM |  |  |  |  |  | 0.01
R52 | PCM_Resistor_SMD_AKL_R_0402_1005Metric | R |  |  |  | Resistor |  |  |  |  |  | 100K
R53 | PCM_Resistor_SMD_AKL_R_0402_1005Metric | R |  |  |  | Resistor |  |  |  |  |  | 16.9K
R54 | PCM_Resistor_SMD_AKL_R_0402_1005Metric | R |  |  |  | Resistor |  |  |  |  |  | 100K
R55 | PCM_Resistor_SMD_AKL_R_0402_1005Metric | R |  |  |  | Resistor |  |  |  |  |  | 16.9K
R56 | Resistor_SMD_R_1206_3216Metric | R |  |  |  | FRM121WFR010TM |  |  |  |  |  | 0.01
R57 | Resistor_SMD_R_1206_3216Metric | R |  |  |  | FRM121WFR010TM |  |  |  |  |  | 0.01
R58 | Resistor_SMD_R_1206_3216Metric | R |  |  |  | FRM121WFR010TM |  |  |  |  |  | 0.01
R6 | PCM_Resistor_SMD_AKL_R_0201_0603Metric | R |  |  |  | Resistor |  |  |  |  |  | 0
R7 | PCM_Resistor_SMD_AKL_R_0201_0603Metric | R |  |  |  | Resistor |  |  |  |  |  | 0
R8 | PCM_Resistor_SMD_AKL_R_0201_0603Metric | R |  |  |  | Resistor |  |  |  |  |  | 0
R9 | PCM_Resistor_SMD_AKL_R_0201_0603Metric | R |  |  |  | Resistor |  |  |  |  |  | 0
SW1 | Button_Switch_SMD_SW_SPST_B3U-1000P |  |  |  |  | Push button switch, generic, two pins |  |  |  |  |  | TS-1088-AR02016
SW2 | Button_Switch_SMD_SW_SPST_B3U-1000P |  |  |  |  | Push button switch, generic, two pins |  |  |  |  |  | TS-1088-AR02016
TP1 | TestPoint_TestPoint_Pad_D1.5mm |  |  |  |  | test point |  |  |  |  |  | TestPoint
TP10 | TestPoint_TestPoint_Pad_D1.5mm |  |  |  |  | test point |  |  |  |  |  | TestPoint
TP11 | TestPoint_TestPoint_Pad_D1.5mm |  |  |  |  | test point |  |  |  |  |  | TestPoint
TP12 | TestPoint_TestPoint_Pad_D1.5mm |  |  |  |  | test point |  |  |  |  |  | TestPoint
TP13 | TestPoint_TestPoint_Pad_D1.5mm |  |  |  |  | test point |  |  |  |  |  | TestPoint
TP14 | TestPoint_TestPoint_Pad_D1.5mm |  |  |  |  | test point |  |  |  |  |  | TestPoint
TP15 | TestPoint_TestPoint_power |  |  |  |  | test point |  |  |  |  |  | TestPoint
TP16 | TestPoint_TestPoint_power |  |  |  |  | test point |  |  |  |  |  | TestPoint
TP17 | TestPoint_TestPoint_power |  |  |  |  | test point |  |  |  |  |  | TestPoint
TP18 | TestPoint_TestPoint_power |  |  |  |  | test point |  |  |  |  |  | TestPoint
TP19 | TestPoint_TestPoint_power |  |  |  |  | test point |  |  |  |  |  | TestPoint
TP2 | TestPoint_TestPoint_Pad_D1.5mm |  |  |  |  | test point |  |  |  |  |  | TestPoint
TP20 | TestPoint_TestPoint_power |  |  |  |  | test point |  |  |  |  |  | TestPoint
TP21 | TestPoint_TestPoint_power |  |  |  |  | test point |  |  |  |  |  | TestPoint
TP22 | TestPoint_TestPoint_power |  |  |  |  | test point |  |  |  |  |  | TestPoint
TP23 | TestPoint_TestPoint_power |  |  |  |  | test point |  |  |  |  |  | TestPoint
TP24 | TestPoint_TestPoint_power |  |  |  |  | test point |  |  |  |  |  | TestPoint
TP25 | TestPoint_TestPoint_power |  |  |  |  | test point |  |  |  |  |  | TestPoint
TP26 | TestPoint_TestPoint_power |  |  |  |  | test point |  |  |  |  |  | TestPoint
TP3 | TestPoint_TestPoint_Pad_D1.5mm |  |  |  |  | test point |  |  |  |  |  | TestPoint
TP4 | TestPoint_TestPoint_Pad_D1.5mm |  |  |  |  | test point |  |  |  |  |  | TestPoint
TP5 | TestPoint_TestPoint_Pad_D1.5mm |  |  |  |  | test point |  |  |  |  |  | TestPoint
TP6 | TestPoint_TestPoint_Pad_D1.5mm |  |  |  |  | test point |  |  |  |  |  | TestPoint
TP7 | TestPoint_TestPoint_Pad_D1.5mm |  |  |  |  | test point |  |  |  |  |  | TestPoint
TP8 | TestPoint_TestPoint_Pad_D1.5mm |  |  |  |  | test point |  |  |  |  |  | TestPoint
TP9 | TestPoint_TestPoint_Pad_D1.5mm |  |  |  |  | test point |  |  |  |  |  | TestPoint
U1 | Package_TO_SOT_SMD_SOT-223-3_TabPin2 |  |  |  | http://www.diodes.com/datasheets/AP1117.pdf | 1A Low Dropout regulator, positive, 3.3V fixed output, SOT-223 |  |  |  |  |  | AP1117-33
U10 | TPS55289RYQR_TPS55289RYQR |  | TPS55289RYQR | https://www.arrow.com/en/products/tps55289ryqr/texas-instruments?region=nac | https://www.ti.com/lit/ds/symlink/tps55289.pdf?ts=1664818706180 | 30-V, 8-A buck-boost converter with IC interface | 1 | Texas Instruments | TPS55289RYQR | 595-TPS55289RYQR | https://www.mouser.co.uk/ProductDetail/Texas-Instruments/TPS55289RYQR?qs=T%252BzbugeAwjhgaIN94Lbpjg%3D%3D | TPS55289RYQR
U11 | TPS55289RYQR_TPS55289RYQR |  | TPS55289RYQR | https://www.arrow.com/en/products/tps55289ryqr/texas-instruments?region=nac | https://www.ti.com/lit/ds/symlink/tps55289.pdf?ts=1664818706180 | 30-V, 8-A buck-boost converter with IC interface | 1 | Texas Instruments | TPS55289RYQR | 595-TPS55289RYQR | https://www.mouser.co.uk/ProductDetail/Texas-Instruments/TPS55289RYQR?qs=T%252BzbugeAwjhgaIN94Lbpjg%3D%3D | TPS55289RYQR
U12 | LMR16030_LMR16030 |  | LMR16030SDDAR | https://www.arrow.com/en/products/lmr16030sddar/texas-instruments?utm_currency=USD&region=nac | http://www.ti.com/lit/gpn/lmr16030 | SIMPLE SWITCHER 60V, 3A Step-Down Converter with 40uA Iq | 1.7 | Texas Instruments | LMR16030SDDAR | 595-LMR16030SDDAR | https://www.mouser.co.uk/ProductDetail/Texas-Instruments/LMR16030SDDAR?qs=n%252BTO0c4TDSa4K%2F5N8LGrrw%3D%3D | LMR16030PDDAR
U13 | LMR16030_LMR16030 |  | LMR16030SDDAR | https://www.arrow.com/en/products/lmr16030sddar/texas-instruments?utm_currency=USD&region=nac | http://www.ti.com/lit/gpn/lmr16030 | SIMPLE SWITCHER 60V, 3A Step-Down Converter with 40uA Iq | 1.7 | Texas Instruments | LMR16030SDDAR | 595-LMR16030SDDAR | https://www.mouser.co.uk/ProductDetail/Texas-Instruments/LMR16030SDDAR?qs=n%252BTO0c4TDSa4K%2F5N8LGrrw%3D%3D | LMR16030PDDAR
U2 | Package_DFN_QFN_QFN-32-1EP_5x5mm_P0.5mm_EP3.7x3.7mm |  |  |  | https://www.espressif.com/sites/default/files/documentation/esp32-c3_datasheet_en.pdf | RF Module, ESP32 SoC, RISC-V, WiFi 802.11b/n/g, Bluetooth LE 5, QFN32 |  |  |  |  |  | ESP32-C3
U3 | Package_DFN_QFN_QFN-24-1EP_4x4mm_P0.5mm_EP2.7x2.7mm |  |  |  | https://www.st.com/resource/en/datasheet/stusb4500.pdf | Stand-alone USB PD controller (with sink Auto-run mode), QFN-24 |  |  |  |  |  | STUSB4500QTR
U4 | Package_SO_TSSOP-24_4.4x7.8mm_P0.65mm |  |  |  | https://www.nxp.com/docs/en/data-sheet/PCA9555.pdf | IO expander 16 GPIO, I2C 400kHz, Interrupt, 2.3 - 5.5V, TSSOP-24 |  |  |  |  |  | PCA9555PW
U5 | Package_SO_SOIC-8_5.3x5.3mm_P1.27mm |  |  |  | https://www.winbond.com/resource-files/w25q128jv_dtr%20revc%2003272018%20plus.pdf | 128Mbit / 16MiB Serial Flash Memory, Standard/Dual/Quad SPI, 2.7-3.6V, SOIC-8 |  |  |  |  |  | W25Q128JVS
U6 | Package_TO_SOT_SMD_SOT-23-5 |  |  |  | http://www.ti.com/lit/ds/symlink/ina180.pdf | Current Sense Amplifier, 1 Circuit, Rail-to-Rail, 26V, Gain 50 V/V, SOT-23-5 |  |  |  |  |  | INA180A2
U7 | Package_TO_SOT_SMD_SOT-23-5 |  |  |  | http://www.ti.com/lit/ds/symlink/ina180.pdf | Current Sense Amplifier, 1 Circuit, Rail-to-Rail, 26V, Gain 50 V/V, SOT-23-5 |  |  |  |  |  | INA180A2
U8 | Package_TO_SOT_SMD_SOT-23-5 |  |  |  | http://www.ti.com/lit/ds/symlink/ina180.pdf | Current Sense Amplifier, 1 Circuit, Rail-to-Rail, 26V, Gain 50 V/V, SOT-23-5 |  |  |  |  |  | INA180A2
U9 | Package_TO_SOT_SMD_SOT-23-5 |  |  |  | http://www.ti.com/lit/ds/symlink/ina180.pdf | Current Sense Amplifier, 1 Circuit, Rail-to-Rail, 26V, Gain 50 V/V, SOT-23-5 |  |  |  |  |  | INA180A2
UNNAMED118 | _
UNNAMED159 | _
UNNAMED31 | _
UNNAMED65 | _
Y1 | Crystal_Crystal_SMD_3225-4Pin_3.2x2.5mm |  |  |  |  | Four pin crystal, GND on pins 2 and 4, small symbol |  |  |  |  |  | X322540MPB4SI
kibuzzard-689E2C41 | _kibuzzard-689E2C41 |  |  |  |  |  |  |  |  |  |  | G***
C19 | Capacitor_SMD_C_0402_1005Metric | C |  |  |  | Unpolarized capacitor |  |  |  |  |  | 1uF
C20 | Capacitor_SMD_C_0402_1005Metric | C |  |  |  | Unpolarized capacitor |  |  |  |  |  | 1uF
C21 | Capacitor_SMD_C_0402_1005Metric | C |  |  |  | Unpolarized capacitor |  |  |  |  |  | 1uF
C22 | Capacitor_SMD_C_0805_2012Metric | C |  |  |  | Unpolarized capacitor |  |  |  |  |  | 22uF | 25V
C23 | Capacitor_SMD_C_0805_2012Metric | C |  |  |  | Unpolarized capacitor |  |  |  |  |  | 22uF | 25V
C24 | Capacitor_SMD_C_0805_2012Metric | C |  |  |  | Unpolarized capacitor |  |  |  |  |  | 22uF | 25V
C32 | Capacitor_SMD_C_0402_1005Metric | C |  |  |  | Unpolarized capacitor |  |  |  |  |  | 100nF
C33 | Capacitor_SMD_C_0402_1005Metric | C |  |  |  | Unpolarized capacitor |  |  |  |  |  | 100nF
C34 | Capacitor_SMD_C_0805_2012Metric | C |  |  |  | Unpolarized capacitor |  |  |  |  |  | 22uF | 25V
C35 | Capacitor_SMD_C_0805_2012Metric | C |  |  |  | Unpolarized capacitor |  |  |  |  |  | 22uF | 25V
C37 | Capacitor_SMD_C_0805_2012Metric | C |  |  |  | Unpolarized capacitor |  |  |  |  |  | 22uF | 25V
C38 | Capacitor_SMD_C_0805_2012Metric | C |  |  |  | Unpolarized capacitor |  |  |  |  |  | 22uF | 25V
C39 | Capacitor_SMD_C_0805_2012Metric | C |  |  |  | Unpolarized capacitor |  |  |  |  |  | 22uF | 25V
C40 | Capacitor_SMD_C_0805_2012Metric | C |  |  |  | Unpolarized capacitor |  |  |  |  |  | 22uF | 25V
C45 | Capacitor_SMD_C_0805_2012Metric | C |  |  |  | Unpolarized capacitor |  |  |  |  |  | 22uF | 25V
C46 | Capacitor_SMD_C_0805_2012Metric | C |  |  |  | Unpolarized capacitor |  |  |  |  |  | 22uF | 25V
C47 | Capacitor_SMD_C_0805_2012Metric | C |  |  |  | Unpolarized capacitor |  |  |  |  |  | 22uF | 25V
C48 | Capacitor_SMD_C_0805_2012Metric | C |  |  |  | Unpolarized capacitor |  |  |  |  |  | 22uF | 25V
G*** | _LOGO |  |  |  |  |  |  |  |  |  |  | LOGO

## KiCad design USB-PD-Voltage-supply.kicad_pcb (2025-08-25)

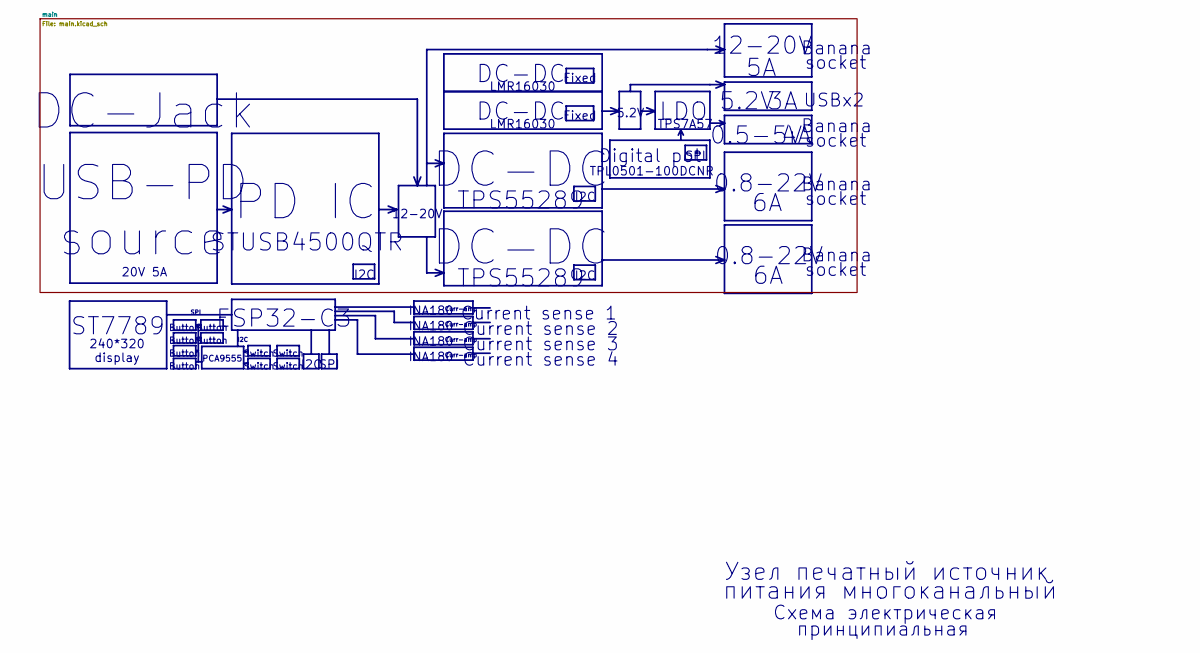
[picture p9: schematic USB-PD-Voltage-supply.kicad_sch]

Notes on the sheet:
Curr-amp
PD IC
питания многоканальный
TPS7A57
socket
I2C
INA180
Button
USBx2
Fixed
0.8-22V
12-20V
Banana
TPS55289
5.2V
Current sense 2
LMR16030
STUSB4500QTR
Current sense 1
LDO
SPI
240*320 display
Узел печатный источник
Digital pot
Switch
DC-DC
20V 5A
DC-Jack
USB-PD source
TPL0501-100DCNR
ST7789
PCA9555
Current sense 4
Схема электрическая
принципиальная
0.5-5V
Current sense 3
ESP32-C3

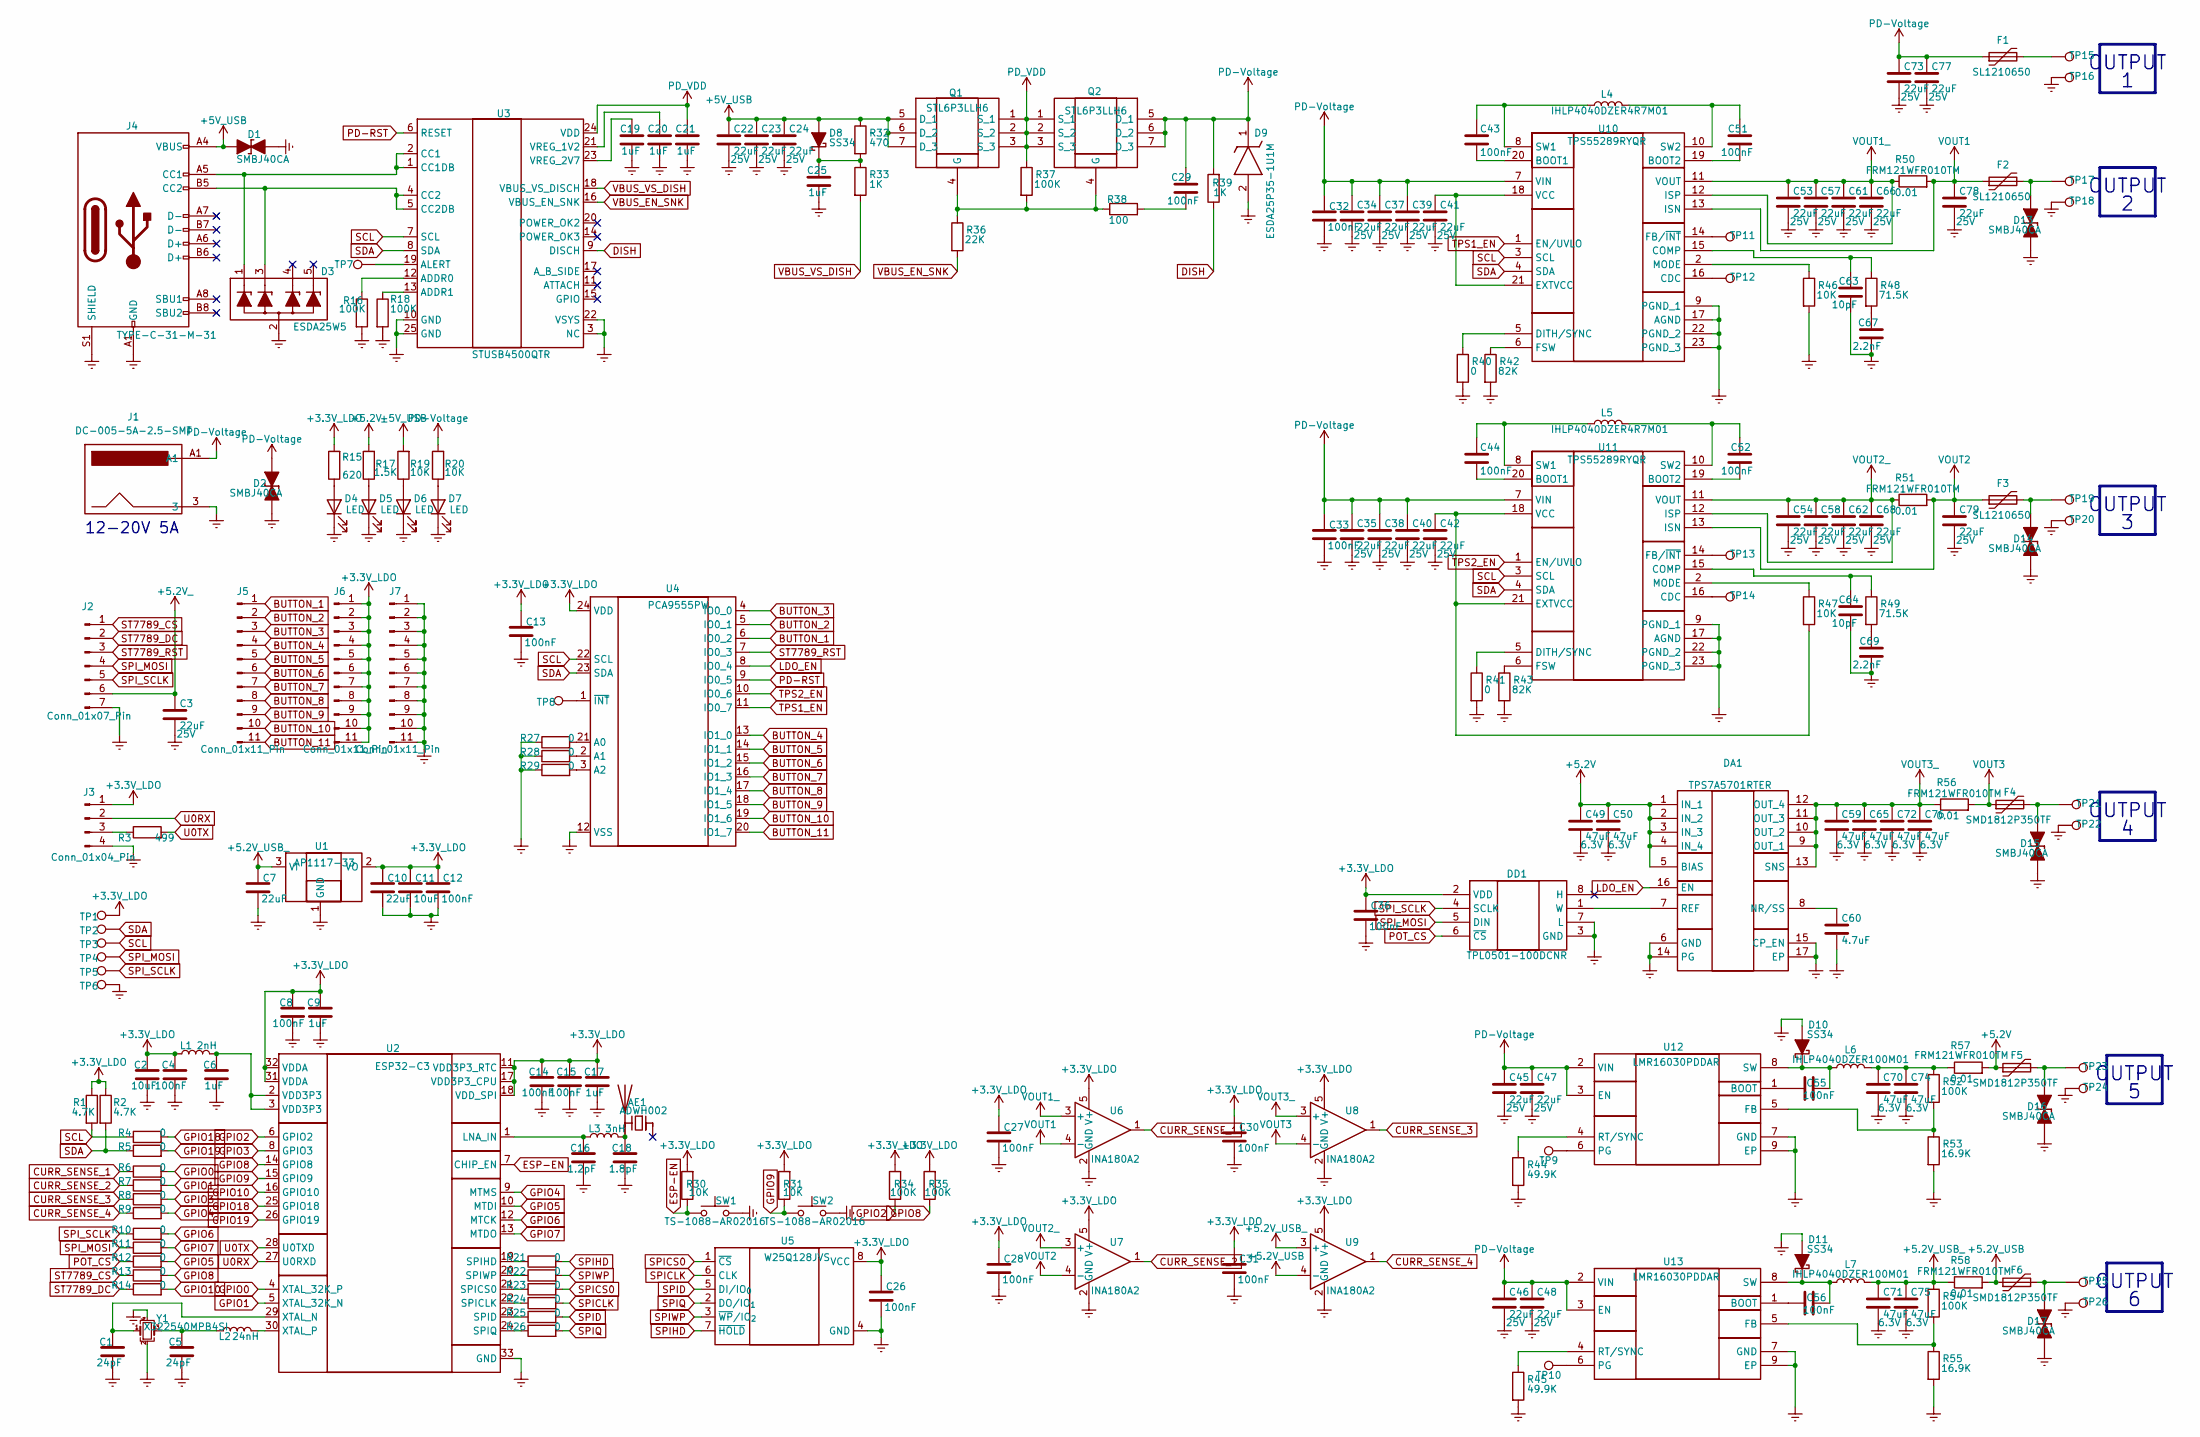
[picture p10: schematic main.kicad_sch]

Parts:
AE1: ADWH002; R_1206_3216Metric
C1, C5: 24pF; C_0201_0603Metric
C2, C11: 10uF; C_0402_1005Metric
C3, C22, C23, C24, C34, C35, C37, C38, C39, C40, C41, C42, C45, C46, C47, C48, C53, C54, C57, C58, C61, C62, C66, C68, C73, C77, C78, C79: 22uF; C_0805_2012Metric; Voltage 25V
C4, C8, C14, C15: 100nF; C_0201_0603Metric
C6, C9, C17: 1uF; C_0201_0603Metric
C7, C10: 22uF; C_0402_1005Metric
C12, C13, C26, C27, C28, C29, C30, C31, C32, C33, C36, C43, C44, C51, C52, C55, C56: 100nF; C_0402_1005Metric
C16: 1.2pF; C_0201_0603Metric
C18: 1.8pF; C_0201_0603Metric
C19, C20, C21, C25: 1uF; C_0402_1005Metric
C49, C50, C59, C65, C70, C71, C72, C74, C75, C76: 47uF; C_0805_2012Metric; Voltage 6.3V
C60: 4.7uF; C_0402_1005Metric; Voltage 6.3V
C63, C64: 10pF; C_0402_1005Metric
C67, C69: 2.2nF; C_0402_1005Metric
D1, D2, D13, D14, D15, D16, D17: SMBJ40CA; D_SMB_TVS
D3: ESDA25W5; SOT-353_SC-70-5
D4, D5, D6, D7: LED; LED_0402_1005Metric
D8, D10, D11: SS34; D_SMA
D9: ESDA25P35-1U1M; ESDA25P351U1M; Manufacturer_Part_Number ESDA25P35-1U1M; Mouser Part Number 511-ESDA25P35-1U1M
DA1: TPS7A5701RTER; TPS7A57; Manufacturer_Part_Number TPS7A5701RTER; Mouser Part Number 595-TPS7A5701RTER
DD1: TPL0501-100DCNR; SOT65P280X145-8N; Manufacturer_Part_Number TPL0501-100DCNR; Mouser Part Number 595-TPL0501-100DCNR
F1, F2, F3: SL1210650; Fuse_1210_3225Metric
F4, F5, F6: SMD1812P350TF; Fuse_1812_4532Metric
J1: DC-005-5A-2.5-SMT; DC-005-5A; Manufacturer_Part_Number DC-005-5A-2.5-SMT
J2: Conn_01x07_Pin; PinHeader_1x07_P1.27mm_Vertical
J3: Conn_01x04_Pin; PinSocket_1x04_P2.54mm_Vertical
J4: TYPE-C-31-M-31; USB_C_Receptacle_G-Switch_GT-USB-7010ASV
J5, J6, J7: Conn_01x11_Pin; PinHeader_1x11_P1.27mm_Vertical
L1: 2nH; L_0402_1005Metric
L2: 24nH; L_0201_0603Metric
L3: 3nH; L_0201_0603Metric
L4, L5: IHLP4040DZER4R7M01; L_APV_APH1040
L6, L7: IHLP4040DZER100M01; L_APV_APH1040
Q1, Q2: STL6P3LLH6; STL8N10F7; Manufacturer_Part_Number STL6P3LLH6; Mouser Part Number 511-STL6P3LLH6
R1, R2: 4.7K; R_0201_0603Metric
R3: 499; R_0201_0603Metric
R4, R5, R6, R7, R8, R9, R10, R11, R12, R13, R14, R21, R22, R23, R24, R25, R26, R27, R28, R29: 0; R_0201_0603Metric
R15: 620; R_0402_1005Metric
R16, R18, R37, R52, R54: 100K; R_0402_1005Metric
R17: 1.5K; R_0402_1005Metric
R19, R20, R46, R47: 10K; R_0402_1005Metric
R30, R31: 10K; R_0201_0603Metric
R32: 470; R_0402_1005Metric
R33, R39: 1K; R_0402_1005Metric
R34, R35: 100K; R_0201_0603Metric
R36: 22K; R_0402_1005Metric
R38: 100; R_0402_1005Metric
R40, R41: 0; R_0402_1005Metric
R42, R43: 82K; R_0402_1005Metric
R44, R45: 49.9K; R_0402_1005Metric
R48, R49: 71.5K; R_0402_1005Metric
R50, R51, R56, R57, R58: 0.01; R_1206_3216Metric
R53, R55: 16.9K; R_0402_1005Metric
SW1, SW2: TS-1088-AR02016; SW_SPST_B3U-1000P
TP1, TP2, TP3, TP4, TP5, TP6, TP7, TP8, TP9, TP10, TP11, TP12, TP13, TP14: TestPoint; TestPoint_Pad_D1.5mm
TP15, TP16, TP17, TP18, TP19, TP20, TP21, TP22, TP23, TP24, TP25, TP26: TestPoint; TestPoint_power
U1: AP1117-33; SOT-223-3_TabPin2
U2: ESP32-C3; QFN-32-1EP_5x5mm_P0.5mm_EP3.7x3.7mm
U3: STUSB4500QTR; QFN-24-1EP_4x4mm_P0.5mm_EP2.7x2.7mm
U4: PCA9555PW; TSSOP-24_4.4x7.8mm_P0.65mm
U5: W25Q128JVS; SOIC-8_5.3x5.3mm_P1.27mm
U6, U7, U8, U9: INA180A2; SOT-23-5
U10, U11: TPS55289RYQR; Manufacturer_Part_Number TPS55289RYQR; Mouser Part Number 595-TPS55289RYQR
U12, U13: LMR16030PDDAR; LMR16030; Manufacturer_Part_Number LMR16030SDDAR; Mouser Part Number 595-LMR16030SDDAR
Y1: X322540MPB4SI; Crystal_SMD_3225-4Pin_3.2x2.5mm

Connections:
+3.3V_LDO: C2.1, C4.1, C8.1, C9.1, C10.1, C11.1, C12.1, C13.1, C14.1, C15.1, C17.1, C26.1, C27.1, C28.1, C30.1, C31.1, C36.1, DD1.2 (VDD), J3.1, J6.1, J6.2, J6.3, J6.4, J6.5, J6.6, J6.7, J6.8, J6.9, J6.10, J6.11, L1.1, R1.1, R2.1, R15.2, R30.2, R31.2, R34.2, R35.2, TP1.1, U1.2 (VO), U2.11 (VDD3P3_RTC), U2.17 (VDD3P3_CPU), U2.18 (VDD_SPI), U2.31 (VDDA), U2.32 (VDDA), U4.24 (VDD), U5.8 (VCC), U6.5 (V+), U7.5 (V+), U8.5 (V+), U9.5 (V+)
+5.2V: C49.1, C50.1, DA1.1 (IN_1), DA1.2 (IN_2), DA1.3 (IN_3), DA1.4 (IN_4), DA1.5 (BIAS), F5.1, R57.2
+5.2V_: C3.1, J2.6, R17.2
+5.2V_USB: F6.1, R58.2, U9.4 (-)
+5.2V_USB_: C7.1, C71.1, C75.1, L7.2, R54.1, R58.1, U1.3 (VI), U9.3 (+)
+5V_USB: C22.1, C23.1, C24.1, D1.2 (A), D8.2 (A), J4.A4 (VBUS), J4.A9 (VBUS), J4.B4 (VBUS), J4.B9 (VBUS), Q1.5 (D_1), Q1.6 (D_2), Q1.7 (D_3), R19.2, R32.1
BUTTON_1: J5.1, U4.6 (IO0_2)
BUTTON_2: J5.2, U4.5 (IO0_1)
BUTTON_3: J5.3, U4.4 (IO0_0)
BUTTON_4: J5.4, U4.13 (IO1_0)
BUTTON_5: J5.5, U4.14 (IO1_1)
BUTTON_6: J5.6, U4.15 (IO1_2)
BUTTON_7: J5.7, U4.16 (IO1_3)
BUTTON_8: J5.8, U4.17 (IO1_4)
BUTTON_9: J5.9, U4.18 (IO1_5)
BUTTON_10: J5.10, U4.19 (IO1_6)
BUTTON_11: J5.11, U4.20 (IO1_7)
CURR_SENSE_1: R6.1, U6.1
CURR_SENSE_2: R7.1, U7.1
CURR_SENSE_3: R8.1, U8.1
CURR_SENSE_4: R9.1, U9.1
DISH: R39.1, U3.9 (DISCH)
ESP-EN: R30.1, SW1.1, U2.7 (CHIP_EN)
Earth: C1.2, C2.2, C3.2, C4.2, C5.2, C6.2, C7.2, C8.2, C9.2, C10.2, C11.2, C12.2, C13.2, C14.2, C15.2, C16.2, C17.2, C18.2, C19.2, C20.2, C21.2, C22.2, C23.2, C24.2, C25.2, C26.2, C27.2, C28.2, C30.2, C31.2, C32.2, C33.2, C34.2, C35.2, C36.2, C37.2, C38.2, C39.2, C40.2, C41.2, C42.2, C45.2, C46.2, C47.2, C48.2, C49.2, C50.2, C53.2, C54.2, C57.2, C58.2, C59.2, C60.2, C61.2, C62.2, C63.2, C64.2, C65.2, C66.2, C67.2, C68.2, C69.2, C70.2, C71.2, C72.2, C73.2, C74.2, C75.2, C76.2, C77.2, C78.2, C79.2, D1.1 (K), D2.1 (K), D3.2 (VN), D4.1 (K), D5.1 (K), D6.1 (K), D7.1 (K), D9.2 (A), D10.2 (A), D11.2 (A), D13.1 (K), D14.1 (K), D15.1 (K), D16.1 (K), D17.1 (K), DA1.6 (GND), DA1.14 (PG), DA1.15 (CP_EN), DA1.17 (EP), DD1.3 (GND), DD1.7 (L), J1.2, J1.3, J2.7, J3.4, J4.A1 (GND), J4.A12 (GND), J4.B1 (GND), J4.B12 (GND), J4.S1 (SHIELD), J7.1, J7.2, J7.3, J7.4, J7.5, J7.6, J7.7, J7.8, J7.9, J7.10, J7.11, R16.2, R18.2, R27.1, R28.1, R29.1, R40.2, R41.2, R42.2, R43.2, R44.2, R45.2, R46.2, R53.2, R55.2, SW1.2, SW2.2, TP6.1, TP16.1, TP18.1, TP20.1, TP22.1, TP24.1, TP26.1, U1.1 (GND), U2.33 (GND), U3.3 (NC), U3.10 (GND), U3.22 (VSYS), U3.25 (GND), U4.12 (VSS), U5.4 (GND), U6.2 (GND), U7.2 (GND), U8.2 (GND), U9.2 (GND), U10.9 (PGND_1), U10.17 (AGND), U10.22 (PGND_2), U10.23 (PGND_3), U11.9 (PGND_1), U11.17 (AGND), U11.22 (PGND_2), U11.23 (PGND_3), U12.7 (GND), U12.9 (EP), U13.7 (GND), U13.9 (EP), Y1.2, Y1.4
GPIO0: R6.2, U2.4 (XTAL_32K_P)
GPIO1: R7.2, U2.5 (XTAL_32K_N)
GPIO2: R34.1, U2.6 (GPIO2)
GPIO3: R8.2, U2.8 (GPIO3)
GPIO4: R9.2, U2.9 (MTMS)
GPIO5: R12.2, U2.10 (MTDI)
GPIO6: R10.2, U2.12 (MTCK)
GPIO7: R11.2, U2.13 (MTDO)
GPIO8: R13.2, R35.1, U2.14 (GPIO8)
GPIO9: R31.1, SW2.1, U2.15 (GPIO9)
GPIO10: R14.2, U2.16 (GPIO10)
GPIO18: R4.2, U2.25 (GPIO18)
GPIO19: R5.2, U2.26 (GPIO19)
LDO_EN: DA1.16 (EN), U4.8 (IO0_4)
unnamed: AE1.2 (PCB_Trace), C18.1, L3.2
unnamed: C5.1, L2.1, Y1.3
unnamed: C6.1, L1.2, U2.2 (VDD3P3), U2.3 (VDD3P3)
unnamed: C29.2, R38.2
unnamed: C67.1, R48.2
unnamed: C69.1, R49.2
unnamed: C70.1, C74.1, L6.2, R52.1, R57.1
unnamed: D3.1 (L1), J4.A5 (CC1), U3.1 (CC1DB), U3.2 (CC1)
unnamed: D3.3 (L2), J4.B5 (CC2), U3.4 (CC2), U3.5 (CC2DB)
unnamed: D4.2 (A), R15.1
unnamed: D5.2 (A), R17.1
unnamed: D6.2 (A), R19.1
unnamed: D7.2 (A), R20.1
unnamed: C25.1, D8.1 (K), R32.2, R33.1
unnamed: C55.2, D10.1 (K), L6.1, U12.8 (SW)
unnamed: C56.2, D11.1 (K), L7.1, U13.8 (SW)
unnamed: D13.2 (A), F2.2, TP17.1
unnamed: D14.2 (A), F3.2, TP19.1
unnamed: D15.2 (A), F4.2, TP21.1
unnamed: D16.2 (A), F5.2, TP23.1
unnamed: D17.2 (A), F6.2, TP25.1
unnamed: C60.1, DA1.8 (NR/SS)
unnamed: DA1.7 (REF), DD1.1 (W)
unnamed: F1.2, TP15.1
unnamed: J3.3, R3.1
unnamed: Q1.4 (G), Q2.4 (G), R36.1, R37.2, R38.1
unnamed: C16.1, L3.1, U2.1 (LNA_IN)
unnamed: R24.1, U2.22 (SPICLK)
unnamed: R23.1, U2.21 (SPICS0)
unnamed: R25.1, U2.23 (SPID)
unnamed: R21.1, U2.19 (SPIHD)
unnamed: R26.1, U2.24 (SPIQ)
unnamed: R22.1, U2.20 (SPIWP)
unnamed: C1.1, U2.29 (XTAL_N), Y1.1
unnamed: L2.2, U2.30 (XTAL_P)
unnamed: R16.1, U3.12 (ADDR0)
unnamed: R18.1, U3.13 (ADDR1)
unnamed: TP7.1, U3.19 (ALERT)
unnamed: C20.1, U3.21 (VREG_1V2)
unnamed: C19.1, U3.23 (VREG_2V7)
unnamed: R27.2, U4.21 (A0)
unnamed: R28.2, U4.2 (A1)
unnamed: R29.2, U4.3 (A2)
unnamed: TP8.1, U4.1 (~INT)
unnamed: C43.2, U10.20 (BOOT1)
unnamed: C51.2, U10.19 (BOOT2)
unnamed: TP12.1, U10.16 (CDC)
unnamed: C63.1, R48.1, U10.15 (COMP)
unnamed: R40.1, U10.5 (DITH/SYNC)
unnamed: C41.1, U10.18 (VCC), U10.21 (EXTVCC)
unnamed: TP11.1, U10.14 (FB/~INT)
unnamed: R42.1, U10.6 (FSW)
unnamed: R46.1, U10.2 (MODE)
unnamed: C43.1, L4.1, U10.8 (SW1)
unnamed: C51.1, L4.2, U10.10 (SW2)
unnamed: C44.2, U11.20 (BOOT1)
unnamed: C52.2, U11.19 (BOOT2)
unnamed: TP14.1, U11.16 (CDC)
unnamed: C64.1, R49.1, U11.15 (COMP)
unnamed: R41.1, U11.5 (DITH/SYNC)
unnamed: C42.1, R47.2, U11.18 (VCC), U11.21 (EXTVCC)
unnamed: TP13.1, U11.14 (FB/~INT)
unnamed: R43.1, U11.6 (FSW)
unnamed: R47.1, U11.2 (MODE)
unnamed: C44.1, L5.1, U11.8 (SW1)
unnamed: C52.1, L5.2, U11.10 (SW2)
unnamed: C55.1, U12.1 (BOOT)
unnamed: R52.2, R53.1, U12.5 (FB)
unnamed: TP9.1, U12.6 (PG)
unnamed: R44.1, U12.4 (RT/SYNC)
unnamed: C56.1, U13.1 (BOOT)
unnamed: R54.2, R55.1, U13.5 (FB)
unnamed: TP10.1, U13.6 (PG)
unnamed: R45.1, U13.4 (RT/SYNC)
PD-RST: U3.6 (RESET), U4.9 (IO0_5)
PD-Voltage: C29.1, C32.1, C33.1, C34.1, C35.1, C37.1, C38.1, C39.1, C40.1, C45.1, C46.1, C47.1, C48.1, C73.1, C77.1, D2.2 (A), D9.1 (K), F1.1, J1.A1, J1.B1, Q2.5 (D_1), Q2.6 (D_2), Q2.7 (D_3), R20.2, R39.2, U10.7 (VIN), U11.7 (VIN), U12.2 (VIN), U12.3 (EN), U13.2 (VIN), U13.3 (EN)
PD_VDD: C21.1, Q1.1 (S_1), Q1.2 (S_2), Q1.3 (S_3), Q2.1 (S_1), Q2.2 (S_2), Q2.3 (S_3), R37.1, U3.24 (VDD)
POT_CS: DD1.6 (~CS), R12.1
SCL: R1.2, R4.1, TP3.1, U3.7 (SCL), U4.22 (SCL), U10.3 (SCL), U11.3 (SCL)
SDA: R2.2, R5.1, TP2.1, U3.8 (SDA), U4.23 (SDA), U10.4 (SDA), U11.4 (SDA)
SPICLK: R24.2, U5.6 (CLK)
SPICS0: R23.2, U5.1 (~CS)
SPID: R25.2, U5.5 (DI/IO_{0})
SPIHD: R21.2, U5.7 (~HOLD)
SPIQ: R26.2, U5.2 (DO/IO_{1})
SPIWP: R22.2, U5.3 (~WP/IO_{2})
SPI_MOSI: DD1.5 (DIN), J2.4, R11.1, TP4.1
SPI_SCLK: DD1.4 (SCLK), J2.5, R10.1, TP5.1
ST7789_CS: J2.1, R13.1
ST7789_DC: J2.2, R14.1
ST7789_RST: J2.3, U4.7 (IO0_3)
TPS1_EN: U4.11 (IO0_7), U10.1 (EN/UVLO)
TPS2_EN: U4.10 (IO0_6), U11.1 (EN/UVLO)
U0RX: J3.2, U2.27 (U0RXD)
U0TX: R3.2, U2.28 (U0TXD)
VBUS_EN_SNK: R36.2, U3.16 (VBUS_EN_SNK)
VBUS_VS_DISH: R33.2, U3.18 (VBUS_VS_DISCH)
VOUT1: C78.1, F2.1, R50.2, U6.4 (-), U10.13 (ISN)
VOUT1_: C53.1, C57.1, C61.1, C66.1, R50.1, U6.3 (+), U10.11 (VOUT), U10.12 (ISP)
VOUT2: C79.1, F3.1, R51.2, U7.4 (-), U11.13 (ISN)
VOUT2_: C54.1, C58.1, C62.1, C68.1, R51.1, U7.3 (+), U11.11 (VOUT), U11.12 (ISP)
VOUT3: F4.1, R56.2, U8.4 (-)
VOUT3_: C59.1, C65.1, C72.1, C76.1, DA1.9 (OUT_1), DA1.10 (OUT_2), DA1.11 (OUT_3), DA1.12 (OUT_4), DA1.13 (SNS), R56.1, U8.3 (+)

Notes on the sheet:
OUTPUT
12-20V 5A

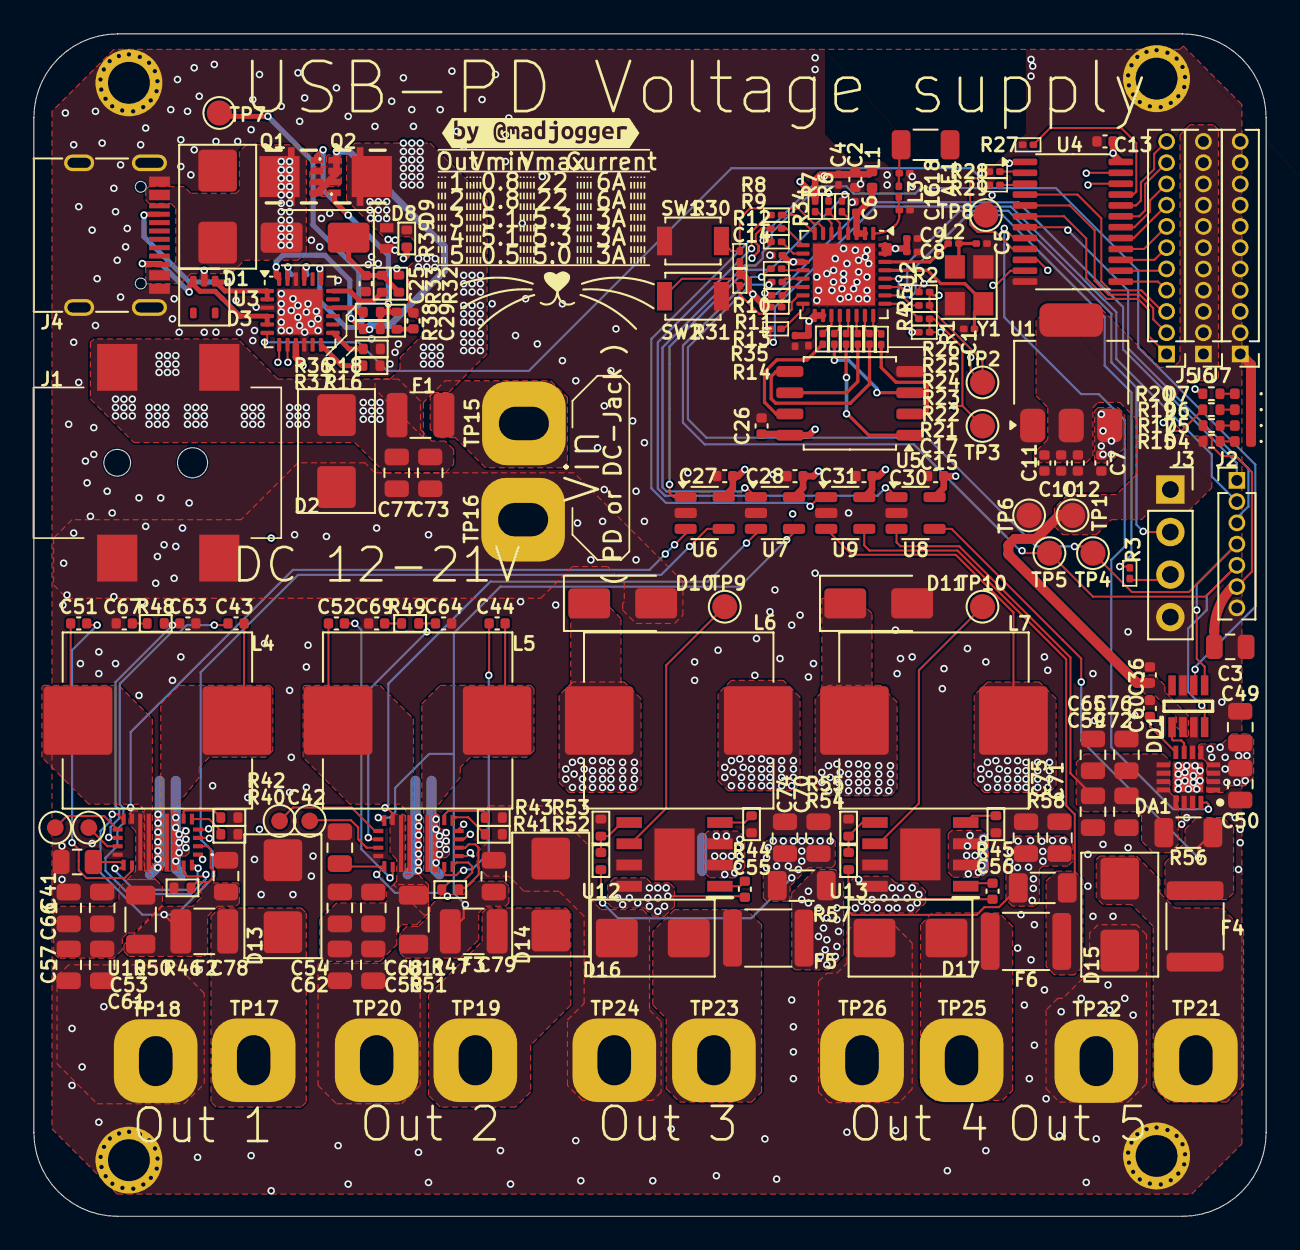
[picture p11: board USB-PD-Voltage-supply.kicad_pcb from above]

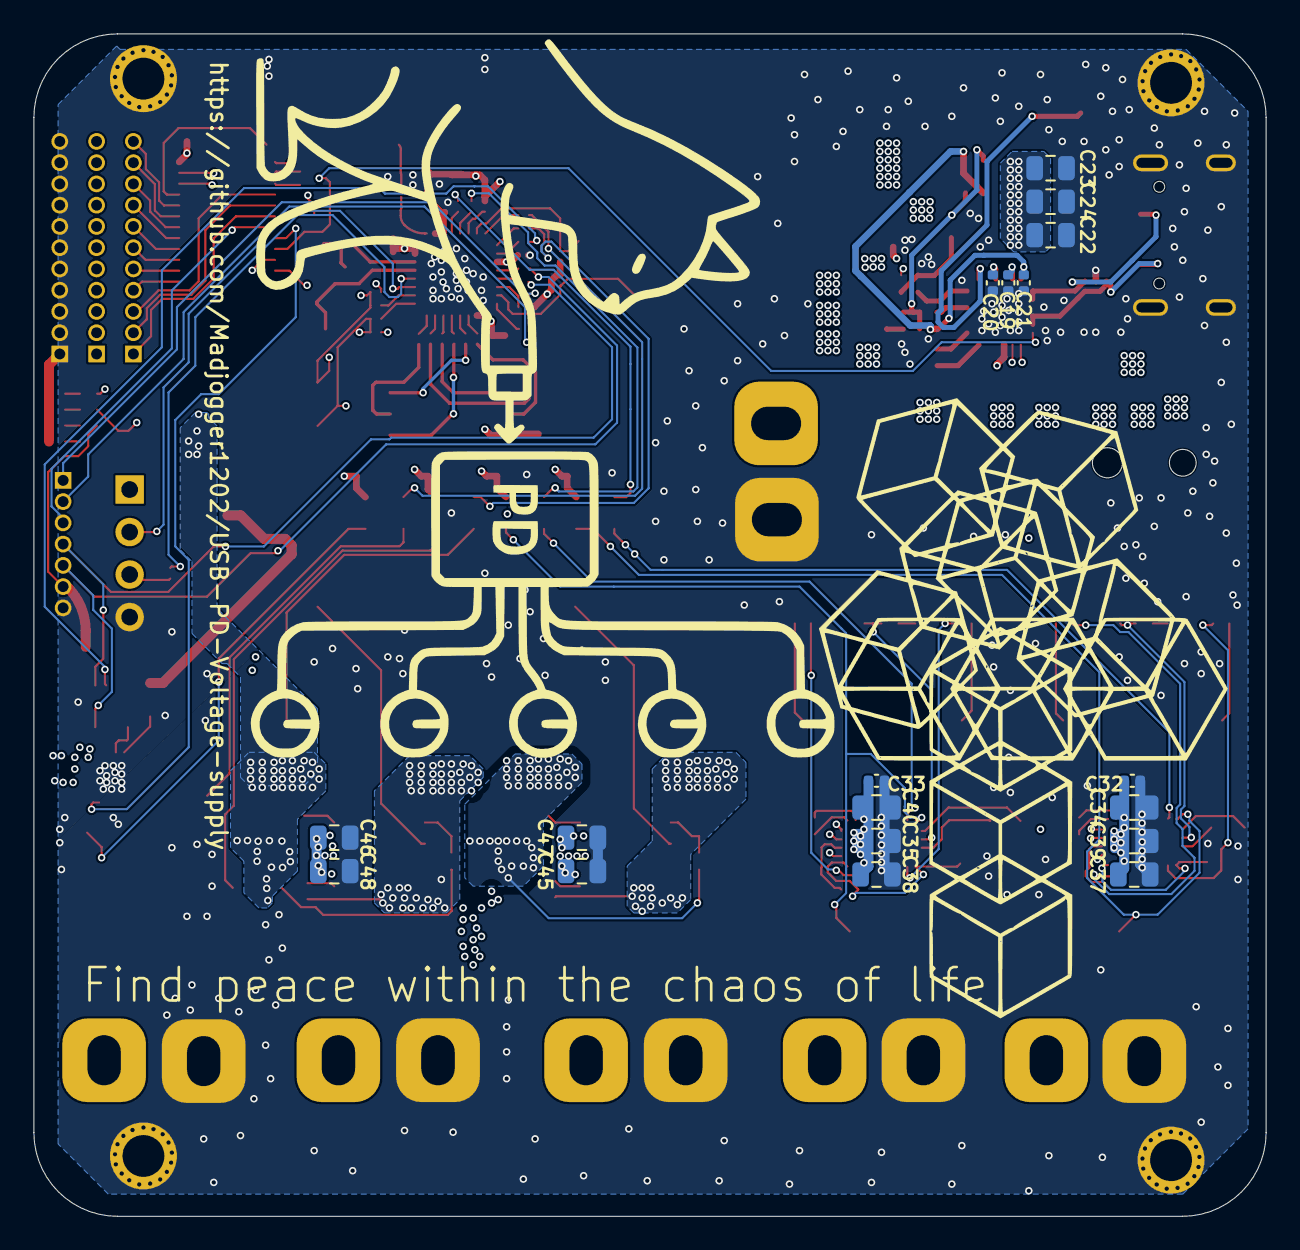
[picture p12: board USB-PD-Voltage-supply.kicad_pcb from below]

Board: 4 copper layers, 73.6 x 70.6 mm, 221 parts (18 on the bottom side), 141 nets.

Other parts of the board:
kibuzzard-689E2C41: G***; kibuzzard-689E2C41

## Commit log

2025-08-07 Начало работы над проектом, готова структурная схема, подобраны компоненты Добавлены необходимые библиотеки
    [USB-PD-Voltage-supply.kicad_pcb, USB-PD-Voltage-supply.kicad_sch]
2025-08-10 Почти завершённая схема
    [Power.kicad_sch, USB-PD-Voltage-supply.kicad_sch]
2025-08-11 Schematics done
    [MCU.kicad_sch, USB-PD-Voltage-supply.kicad_sch, main.kicad_sch]
2025-08-11 upd library + PCB created
    [USB-PD-Voltage-supply.kicad_pcb, main.kicad_sch]
2025-08-11 Added JLCPCB BOM + placed main components on PCB to form a prototype
    [USB-PD-JLCPCB_BOM.xls, USB-PD-Voltage-supply.csv, USB-PD-Voltage-supply.kicad_pcb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]
2025-08-13 Finished components placement + silkscreen placement Reviewed schematics, changed outline Ready for tracing
    [USB-PD-JLCPCB_BOM ( устарел ).xls, USB-PD-Voltage-supply.csv, USB-PD-Voltage-supply.kicad_pcb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]
2025-08-14 power poligons partly done
    [USB-PD-Voltage-supply.kicad_pcb]
2025-08-14 Finished rev0
    [USB-PD-Voltage-supply.kicad_pcb, main.kicad_sch]
2025-08-15 Finished structure and manufacturing files
    [USB-PD-JLCPCB_BOM ( устарел ).xls, USB-PD-JLCPCB_BOM.xls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]
2025-08-18 PCB upd for DFM checking and manufacturing
    [USB-PD-Voltage-supply-B_Cu.gbr, USB-PD-Voltage-supply-B_Mask.gbr, USB-PD-Voltage-supply-B_Paste.gbr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]
2025-08-25 added simulation data for CST + design update ( no important changes )
    [Model.dsn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]
